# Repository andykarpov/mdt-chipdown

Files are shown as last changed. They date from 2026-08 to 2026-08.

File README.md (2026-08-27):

# MicroDEXED Touch Chipdown custom edition

This is an attempt to create a custom PCB of the MicroDEXED Touch (MDT) project to satisfy my own requirements:

- No modules, all chips should be soldered on PCB
- Avoid THT components as much as possible

**Warning! Work in progress. The revB is untested and unreleased yet.**

- Current tested revision: **revA**
- Current dev revision: **revB**

## PCB changelog & ERRATA:

- revA - initial revision
    - Note: Jumpers to select MIDI IN/OUT standard should be removed, instead of them please use 0 Ohm resistors
    - Latest revA contains the following changes: jumpers replaced with solder jumpers
    - The overall display height is slightly higher than expected. Please use 8.5mm standoffs for it. Also the plastic housing from the display pin headers should be removed and the pin height should be reduced to fit the desired connection height of 8.5mm
- revB:
    - 4-layers PCB
    - Replaced teensy module with a set of chips
    - Added additional SD card
    - Added additional LED from the supplementary MCU
    - Changed USB Host power path

## Rev.A Renders

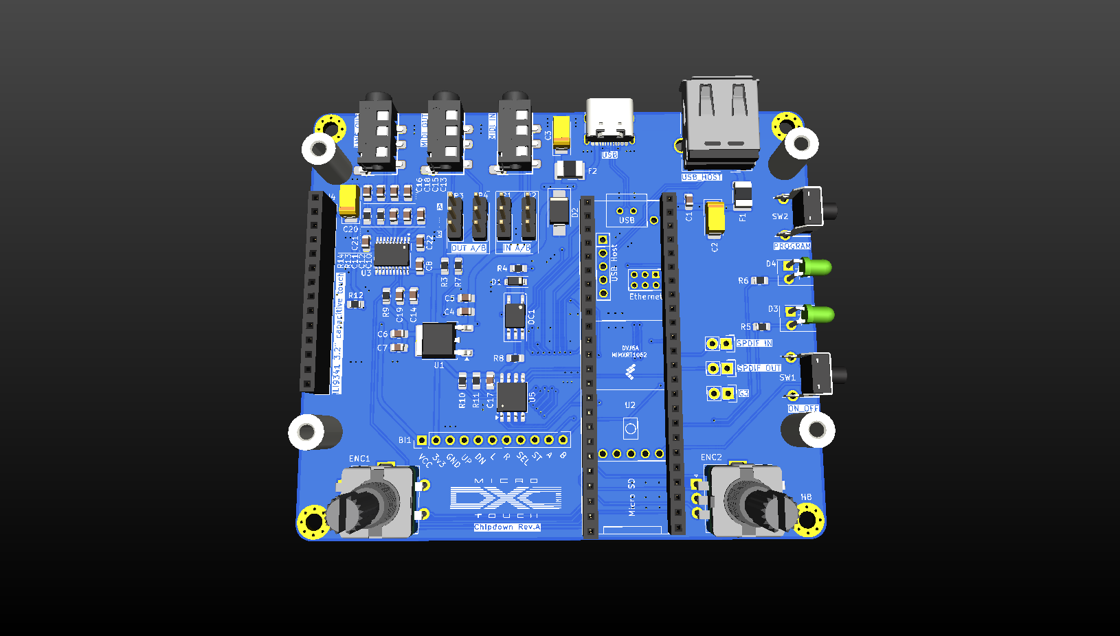
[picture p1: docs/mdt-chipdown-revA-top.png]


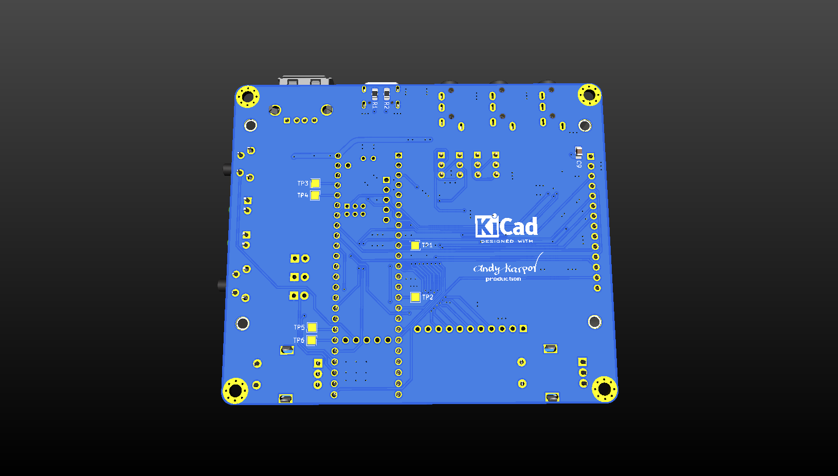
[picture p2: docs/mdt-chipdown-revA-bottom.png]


## Case for rev.A

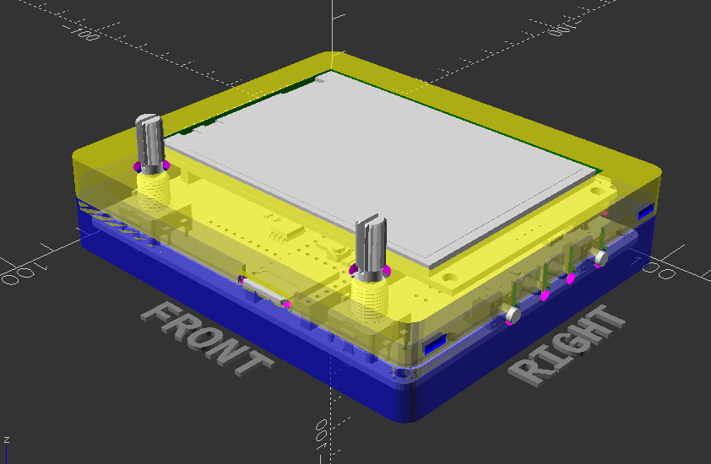
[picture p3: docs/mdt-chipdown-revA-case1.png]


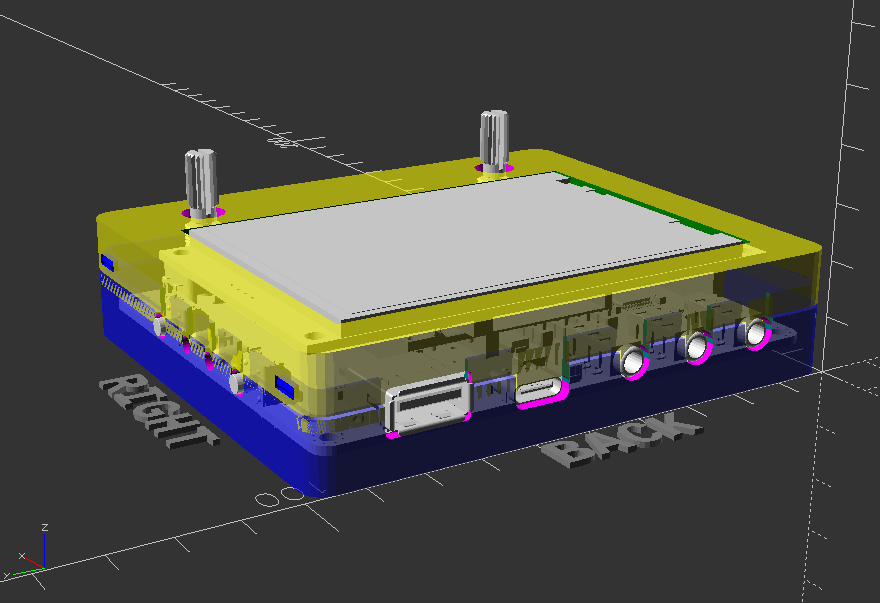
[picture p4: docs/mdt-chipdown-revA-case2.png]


## Rev.B Renders

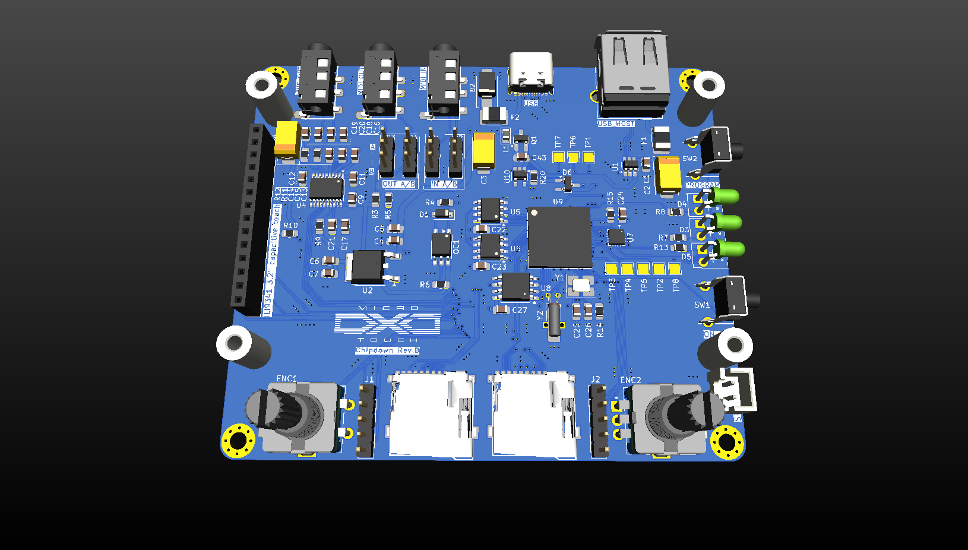
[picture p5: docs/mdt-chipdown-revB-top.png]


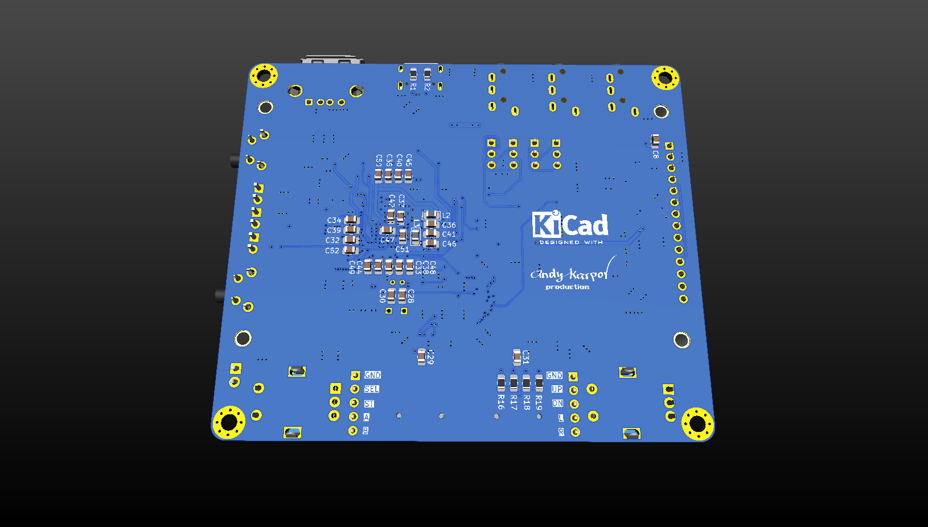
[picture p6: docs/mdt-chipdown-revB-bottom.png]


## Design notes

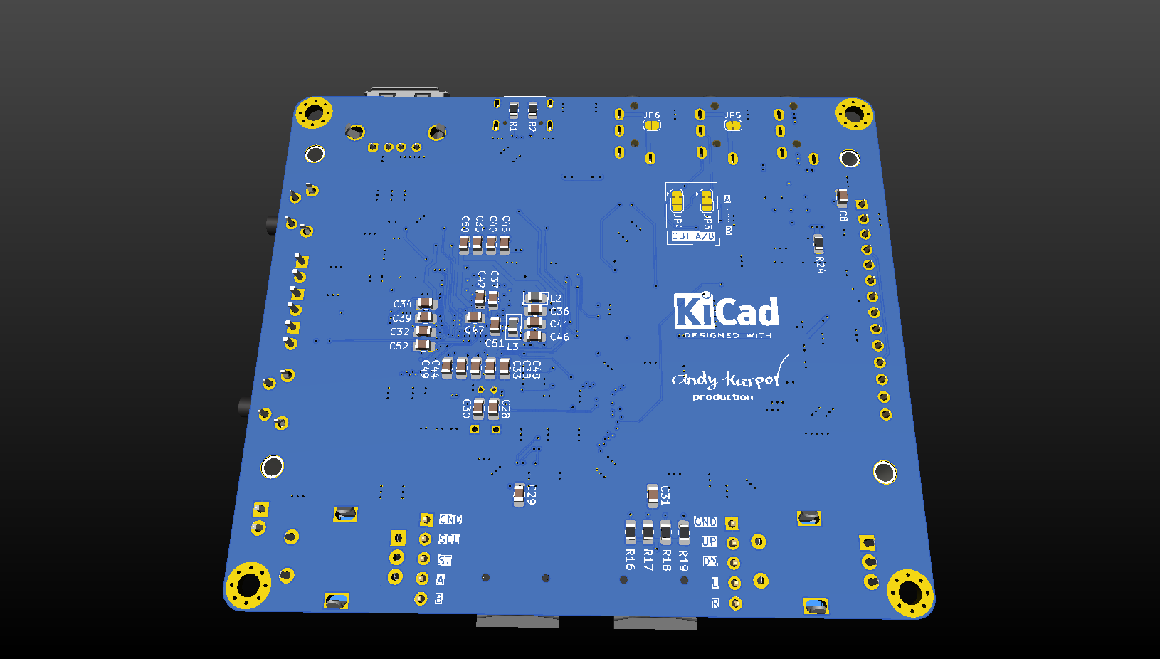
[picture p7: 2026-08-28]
docs/mdt-chipdown-revB1-bottom.png

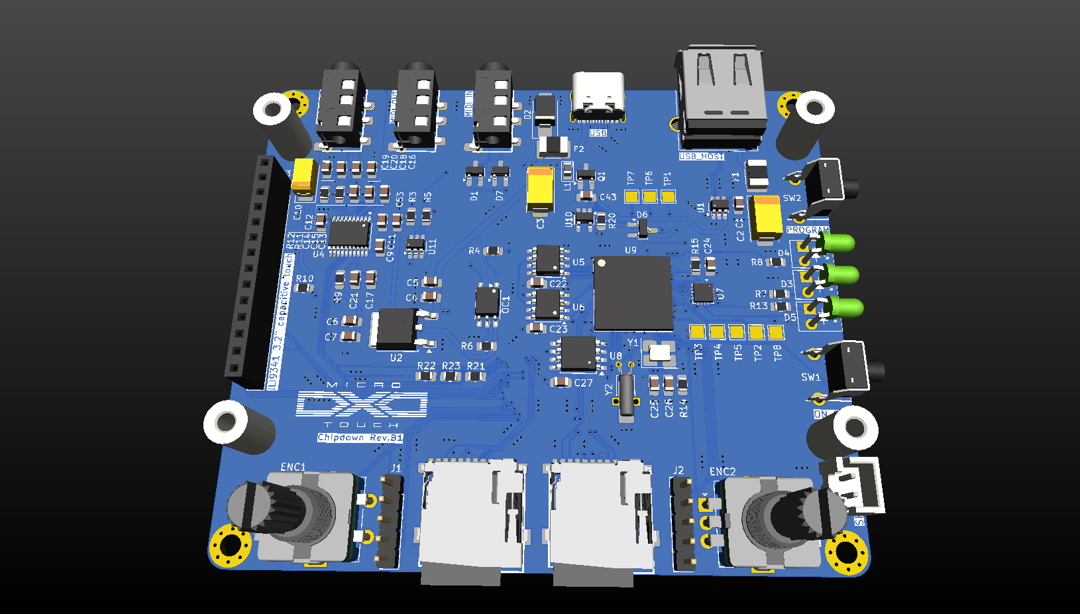
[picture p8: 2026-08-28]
docs/mdt-chipdown-revB1-top.png

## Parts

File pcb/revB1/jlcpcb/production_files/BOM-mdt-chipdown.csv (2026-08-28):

Comment | Designator | Footprint | LCSC | Quantity
0 | R10 | R_0805_2012Metric_Pad1.20x1.40mm_HandSolder | C17477 | 1
100k | R15,R20 | R_0805_2012Metric_Pad1.20x1.40mm_HandSolder | C25611 | 2
100n | C11,C12,C15,C21,C22,C23,C24,C27,C29,C31,C5,C53,C7,C8,C9 | C_0805_2012Metric_Pad1.18x1.45mm_HandSolder | C1711 | 15
100uF | C2,C3 | CP_EIA-7343-31_Kemet-D_HandSolder | C2749 | 2
100uF | C10 | CP_EIA-6032-28_Kemet-C_HandSolder | C8649 | 1
10k | R16,R17,R18,R19 | R_0805_2012Metric_Pad1.20x1.40mm_HandSolder | C17414 | 4
10n | C50,C51 | C_0805_2012Metric_Pad1.18x1.45mm_HandSolder | C1710 | 2
10u | C1,C14,C17,C18,C20,C34,C36,C4,C6 | C_0805_2012Metric_Pad1.18x1.45mm_HandSolder | C15850 | 9
10u | C37 | C_0805_2012Metric | C1713 | 1
12p | C25,C26 | C_0805_2012Metric_Pad1.18x1.45mm_HandSolder | C152848 | 2
1k | R13,R7,R8,R9 | R_0805_2012Metric_Pad1.20x1.40mm_HandSolder | C17513 | 4
20p | C28,C30 | C_0805_2012Metric_Pad1.18x1.45mm_HandSolder | C1727 | 2
220 | R4 | R_0805_2012Metric_Pad1.20x1.40mm_HandSolder | C17557 | 1
220n | C32,C38,C39,C43,C45,C46,C47,C48,C49,C52 | C_0805_2012Metric_Pad1.18x1.45mm_HandSolder | C5378 | 10
24MHz | Y1 | Crystal_SMD_3225-4Pin_3.2x2.5mm_HandSoldering | C15643 | 1
2A | F1,F2 | Fuse_1812_4532Metric_Pad1.30x3.40mm_HandSolder | C20812 | 2
2M2 | R14 | R_0805_2012Metric_Pad1.20x1.40mm_HandSolder | C26113 | 1
2n2 | C16,C19 | C_0805_2012Metric_Pad1.18x1.45mm_HandSolder | C1728 | 2
2u2 | C13,C35 | C_0805_2012Metric_Pad1.18x1.45mm_HandSolder | C19110 | 2
32768 | Y2 | Crystal_C26-LF_D2.1mm_L6.5mm_Horizontal_1EP_style2 | C2236 | 1
47 | R3,R5 | R_0805_2012Metric_Pad1.20x1.40mm_HandSolder | C25315 | 2
470 | R11,R12,R6 | R_0805_2012Metric_Pad1.20x1.40mm_HandSolder | C17710 | 3
4u7 | C33,C40,C41,C42,C44 | C_0805_2012Metric_Pad1.18x1.45mm_HandSolder | C1779 | 5
4u7 | L3 | L_0805_2012Metric_Pad1.15x1.40mm | C63166 | 1
5k1 | R1,R2 | R_0805_2012Metric_Pad1.20x1.40mm_HandSolder | C26023 | 2
74LVC2G06 | U11 | SOT-23-6_Handsoldering | C402162 | 1
AMS1117-3.3 | U2 | TO-252-2 | C41414107 | 1
APS6404L-3SQR | U5,U6 | SOIC-8_3.9x4.9mm_P1.27mm | C5333729 | 2
BAT54C | D6 | SOT-23_Handsoldering | C37704 | 1
BAT54S | D1,D7 | SOT-23_Handsoldering | C7420333 | 2
BI | J1,J2 | PinHeader_1x05_P2.54mm_Vertical | C5156614 | 2
DMG2305UX | Q1 | SOT-23_Handsoldering | C144153 | 1
Ferrite 120 | L1,L2 | L_0805_2012Metric_Pad1.15x1.40mm_HandSolder | C5671 | 2
GD25Q64ESIGR | U8 | SOIC-8_5.3x5.3mm_P1.27mm | C2831359 | 1
ILI9341 3.2" capacitive touch | U3 | PinSocket_1x14_P2.54mm_Vertical | C124407 | 1
LED1 | D3 | LED_Indicator_D3.0mm_W4.6mm_L6.5mm | C17683617 | 1
LED2 | D4 | LED_Indicator_D3.0mm_W4.6mm_L6.5mm | C473837 | 1
LINE OUT | TRS1 | AUDIO_JACK_3.5MM_SMD_TRRS_rounded_mixed | C53447038 | 1
MCU LED | D5 | LED_Indicator_D3.0mm_W4.6mm_L6.5mm | C19188468 | 1
MIDI IN | TRS3 | AUDIO_JACK_3.5MM_SMD_TRRS_rounded_mixed | C53447038 | 1
MIDI OUT | TRS2 | AUDIO_JACK_3.5MM_SMD_TRRS_rounded_mixed | C53447038 | 1
MIMXRT1062DVJ6B | U9 | BGA196C80P14X14_1200X1200X152 | C3216699 | 1
MKL02Z32VFG4 | U7 | QFN-16-1EP_3x3mm_P0.5mm_EP1.9x1.9mm | C2056583 | 1
Micro_SD_Card | J4,J5 | GCT-MEM2055-00-190-01-A | C91145 | 2
ON_OFF | SW1 | Push_PTH_RA_8-020_h7.5mm | C125050 | 1
PCM5102A | U4 | TSSOP-20_4.4x6.5mm_P0.65mm | C107671 | 1
PROGRAM | SW2 | Push_PTH_RA_8-020_h7.5mm | C125050 | 1
Rotary_Encoder_L | ENC1 | RotaryEncoder_Alps_EC11E-Switch_Vertical_H20mm | C7435302 | 1
Rotary_Encoder_R | ENC2 | RotaryEncoder_Alps_EC11E-Switch_Vertical_H20mm | C7435302 | 1
SM6T6V8A | D2 | D_SMB_Handsoldering | C511038 | 1
SPDIF OUT | J3 | Pin_Header_Straight_1x02 | C5360898 | 1
TLP2362 | OC1 | SO-5-6_4.55x3.7mm_P1.27mm | C37658 | 1
TLV75733PDBV | U10 | SOT-23-5_HandSoldering | C485517 | 1
TPD3S014 | U1 | SOT-23-6_Handsoldering | C87384 | 1
USB | USB2 | USB_C_Receptacle_G-Switch_GT-USB-7010ASV | C165948 | 1
USB_HOST | USB1 | USB_A_Molex_67643_Horizontal | C2346 | 1
~ | H8 | MountingHole_M3 |  | 1
~ | H6 | MountingHole_M3 |  | 1
~ | H4 | MountingHole_M3 |  | 1
~ | H2 | MountingHole_M3 |  | 1

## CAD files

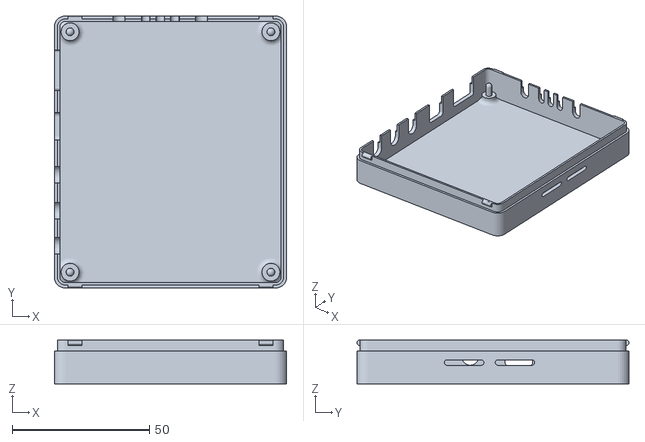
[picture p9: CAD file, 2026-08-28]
case/build/mdt-chipdown-revB-base.stl
84.6 x 99.0 x 16.0

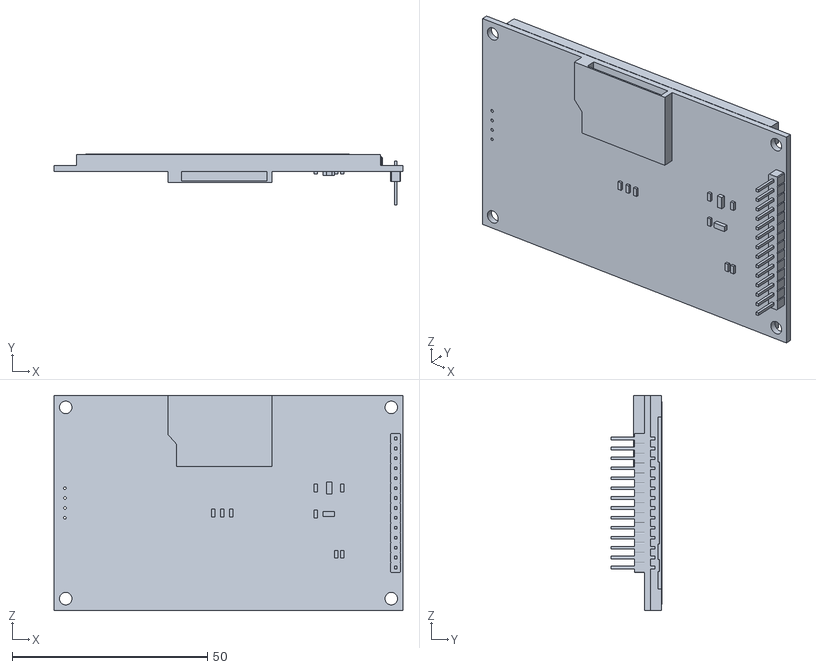
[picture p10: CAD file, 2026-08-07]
case/models/3_2tft.stl
89.4 x 13.1 x 55.1

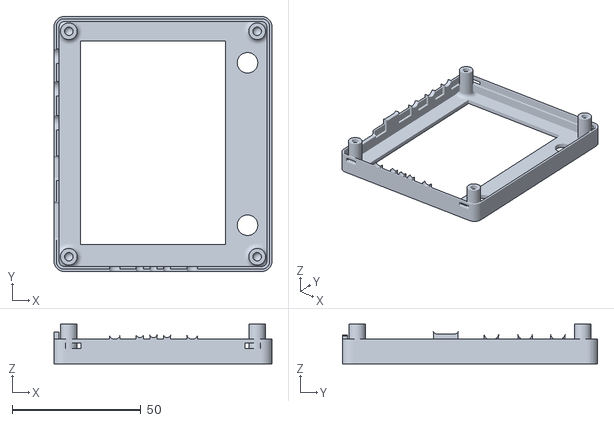
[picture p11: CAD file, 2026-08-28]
case/build/mdt-chipdown-revB-lid.stl
84.6 x 99.0 x 15.5

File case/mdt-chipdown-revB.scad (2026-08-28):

//---------------------------------------------------------
// Yet Another Parameterized Projectbox generator
//
//  This will generate a projectbox for a "MDT Chipdown rev.A"
//
//  Version 3.0 (02-12-2023)
//
// This design is parameterized based on the size of a PCB.
//---------------------------------------------------------
include <./library/YAPPgenerator_v3.scad>

// Note: length/lengte refers to X axis, 
//       width/breedte to Y, 
//       height/hoogte to Z

/*
      padding-back|<------pcb length --->|<padding-front
                            RIGHT
        0    X-as ---> 
        +----------------------------------------+   ---
        |                                        |    ^
        |                                        |   padding-right 
        |                                        |    v
        |    -5,y +----------------------+       |   ---              
 B    Y |         | 0,y              x,y |       |     ^              F
 A    - |         |                      |       |     |              R
 C    a |         |                      |       |     | pcb width    O
 K    s |         |                      |       |     |              N
        |         | 0,0              x,0 |       |     v              T
      ^ |   -5,0  +----------------------+       |   ---
      | |                                        |    padding-left
      0 +----------------------------------------+   ---
        0    X-as --->
                          LEFT
*/

//-- which half do you want to print?
printBaseShell    = true;
printLidShell     = true;
printSwitchExtenders  = false;
printPCB = true;


myPcb = "./models/mdt-chipdown-revB.stl";
myDispPcb = "./models/3_2tft.stl";
offsetDisp = 11+1.6;

if (printPCB)
{
  translate([-31.4, -45.7, 5.1]) 
  {
    rotate([0,0,90]) color("lightgray") import(myPcb);
  }
  
  translate([66.0, 93.6, offsetDisp-3.4]) 
  {
    rotate([90,0,-90]) color("lightgray") import(myDispPcb);
  }
  
}

//-- Edit these parameters for your own board dimensions
wallThickness       = 2;
basePlaneThickness  = 2;
lidPlaneThickness   = 2;

//-- Total height of box = basePlaneThickness + lidPlaneThickness 
//--                     + baseWallHeight + lidWallHeight
//-- space between pcb and lidPlane :=
//--      (baseWallHeight+lidWall_heigth) - (standoff_heigth+pcbThickness)
//--      (6.2 + 4.5) - (3.5 + 1.5) ==> 5.7
baseWallHeight    = 14;
lidWallHeight     = 4.1;

//-- pcb dimensions
pcbLength         = 79.6;
pcbWidth          = 94;
pcbThickness      = 1.6;
                            
//-- padding between pcb and inside wall
paddingFront      = 0.5;
paddingBack       = 0.5;
paddingRight      = 0.5;
paddingLeft       = 0.5;

//-- ridge where base and lid off box can overlap
//-- Make sure this isn't less than lidWallHeight
ridgeHeight       = 4;
ridgeSlack          = 0.2;
roundRadius       = 4.0;
boxType             = 3; // was 0 

//-- How much the PCB needs to be raised from the base
//-- to leave room for solderings and whatnot
standoffHeight    = 3;
standoffPinDiameter = 2.9;
standoffDiameter  = 6.5;

// Set the layer height of your printer
printerLayerHeight  = 0.1; // 0.2


//-- C O N T R O L -------------//-> Default ---------
showSideBySide      = false;     //-> true
previewQuality      = 5;        //-> from 1 to 32, Default = 5
renderQuality       = 8;        //-> from 1 to 32, Default = 8
onLidGap            = 0;
shiftLid            = 1;
hideLidWalls        = false;    //-> false
colorLid            = "yellow";  
alphaLid                  = 0.6;
hideBaseWalls       = false;    //-> false
colorBase           = "blue";
alphaBase           = 0.4;
showPCB             = false;
showSwitches        = false;
showPCBmarkers      = false;
showShellZero       = false;
showCenterMarkers   = false;
inspectX            = 0;        //-> 0=none (>0 from Back)
inspectY            = 0;        //-> 0=none (>0 from Right)
inspectZ            = 0.0;        //-> 0=none (>0 from Bottom)
inspectXfromBack    = false;     //-> View from the inspection cut foreward
inspectYfromLeft    = true;     //-> View from the inspection cut to the right
inspectZfromTop     = true;    //-> View from the inspection cut down
//-- C O N T R O L ---------------------------------------


//===================================================================
// *** PCB Supports ***
// Pin and Socket standoffs 
//-------------------------------------------------------------------
//  Default origin =  yappCoordPCB : pcb[0,0,0]
//
//  Parameters:
//   Required:
//    (0) = posx
//    (1) = posy
//   Optional:
//    (2) = Height to bottom of PCB : Default = standoffHeight
//    (3) = PCB Gap : Default = -1 : Default for yappCoordPCB=pcbThickness, yappCoordBox=0
//    (4) = standoffDiameter    Default = standoffDiameter;
//    (5) = standoffPinDiameter Default = standoffPinDiameter;
//    (6) = standoffHoleSlack   Default = standoffHoleSlack;
//    (7) = filletRadius (0 = auto size)
//    (n) = { <yappBoth> | yappLidOnly | yappBaseOnly }
//    (n) = { yappHole, <yappPin> } // Baseplate support treatment
//    (n) = { <yappAllCorners> | yappFrontLeft | yappFrontRight | yappBackLeft | yappBackRight }
//    (n) = { yappCoordBox, <yappCoordPCB> }  
//    (n) = { yappNoFillet }
//-------------------------------------------------------------------
pcbStands = 
[
  [3.25, 3.25, yappBoth, yappPin, yappAllCorners], // pcb corners
/*  [32.05, 4.06, yappBoth, yappHole, yappFrontLeft, yappFrontRight, yappNoFillet], // front 
  [45.16, 4.06, yappBoth, yappPin, yappBackLeft, yappBackRight, yappNoFillet], // back
  */
];

/*connectors   =  
[
    [4.06, 4.06, 0, 3.5, 5, 3, 5, yappCoordPCB],
    [pcbLength-4.06, 4.06, 0, 3.5, 5, 3, 5, yappCoordPCB],
    [pcbLength-4.06, pcbWidth-4.06, 0, 3.5, 5, 3, 5, yappCoordPCB],
    [4.06, pcbWidth-4.06, 0, 3.5, 5, 3, 5, yappCoordPCB],
];*/

//===================================================================
//  *** Cutouts ***
//    There are 6 cutouts one for each surface:
//      cutoutsBase (Bottom), cutoutsLid (Top), cutoutsFront, cutoutsBack, cutoutsLeft, cutoutsRight
//-------------------------------------------------------------------
//  Default origin = yappCoordBox: box[0,0,0]
//
//                        Required                Not Used        Note
//                      +-----------------------+---------------+------------------------------------
//  yappRectangle       | width, length         | radius        |
//  yappCircle          | radius                | width, length |
//  yappRoundedRect     | width, length, radius |               |     
//  yappCircleWithFlats | width, radius         | length        | length=distance between flats
//  yappCircleWithKey   | width, length, radius |               | width = key width length=key depth
//  yappPolygon         | width, length         | radius        | yappPolygonDef object must be provided
//
//  Parameters:
//   Required:
//    (0) = from Back
//    (1) = from Left
//    (2) = width
//    (3) = length
//    (4) = radius
//    (5) = shape : {yappRectangle | yappCircle | yappPolygon | yappRoundedRect | yappCircleWithFlats | yappCircleWithKey}
//  Optional:
//    (6) = depth : Default = 0/Auto : 0 = Auto (plane thickness)
//    (7) = angle : Default = 0
//    (n) = { yappPolygonDef } : Required if shape = yappPolygon specified -
//    (n) = { yappMaskDef } : If a yappMaskDef object is added it will be used as a mask for the cutout.
//    (n) = { [yappMaskDef, hOffset, vOffst, rotation] } : If a list for a mask is added it will be used as a mask for the cutout. With the Rotation and offsets applied. This can be used to fine tune the mask placement within the opening.
//    (n) = { <yappCoordBox> | yappCoordPCB }
//    (n) = { <yappOrigin>, yappCenter }
//  (n) = { yappLeftOrigin, <yappGlobalOrigin> } // Only affects Top(lid), Back and Right Faces
//-------------------------------------------------------------------
cutoutsLid =  
[
    [72.6, 15.5, 0, 0, 4.0, yappCircle, yappCenter, yappCoordPCB], // ENC1
    [72.6, 78.5, 0, 0, 4.0, yappCircle, yappCenter, yappCoordPCB], // ENC2
];
              
//-- base plane    -- origin is pcb[0,0,0]
// (0) = posx
// (1) = posy
cutoutsBase =   
[
];

//-- back plane  -- origin is pcb[0,0,0]
// (0) = posy
// (1) = posz
cutoutsBack = 
[
    [76.8, 4.2, 14.8, 8, 1, yappRoundedRect, yappCenter, yappCoordPCB], // USB Host
    [56.4, 1.8, 10, 4, 1.5, yappRoundedRect, yappCenter, yappCoordPCB], // usb-c
    [38.7, 3.2, 0, 0, 3.0, yappCircle, yappCenter, yappCoordPCB], // Midi in
    [25.6, 3.2, 0, 0, 3.0, yappCircle, yappCenter, yappCoordPCB], // Audio
    [12.9, 3.2, 0, 0, 3.0, yappCircle, yappCenter, yappCoordPCB], // Midi out
];

ridgeExtBack = 
[
    [71.9, 14.8, 7.8, yappCoordBox], // up on usb-a
    [53.9, 10.0, 8.8, yappCoordBox], // up on usb-c
    [38.2, 6, 9.8, yappCoordBox], // Midi in
    [25.1, 6, 9.8, yappCoordBox], // Midi out
    [12.4, 6, 9.8, yappCoordBox], // Audio out
];
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

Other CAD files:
case/build/mdt-chipdown-revA-base.stl
case/build/mdt-chipdown-revA-lid.stl
case/mdt-chipdown-revA.scad

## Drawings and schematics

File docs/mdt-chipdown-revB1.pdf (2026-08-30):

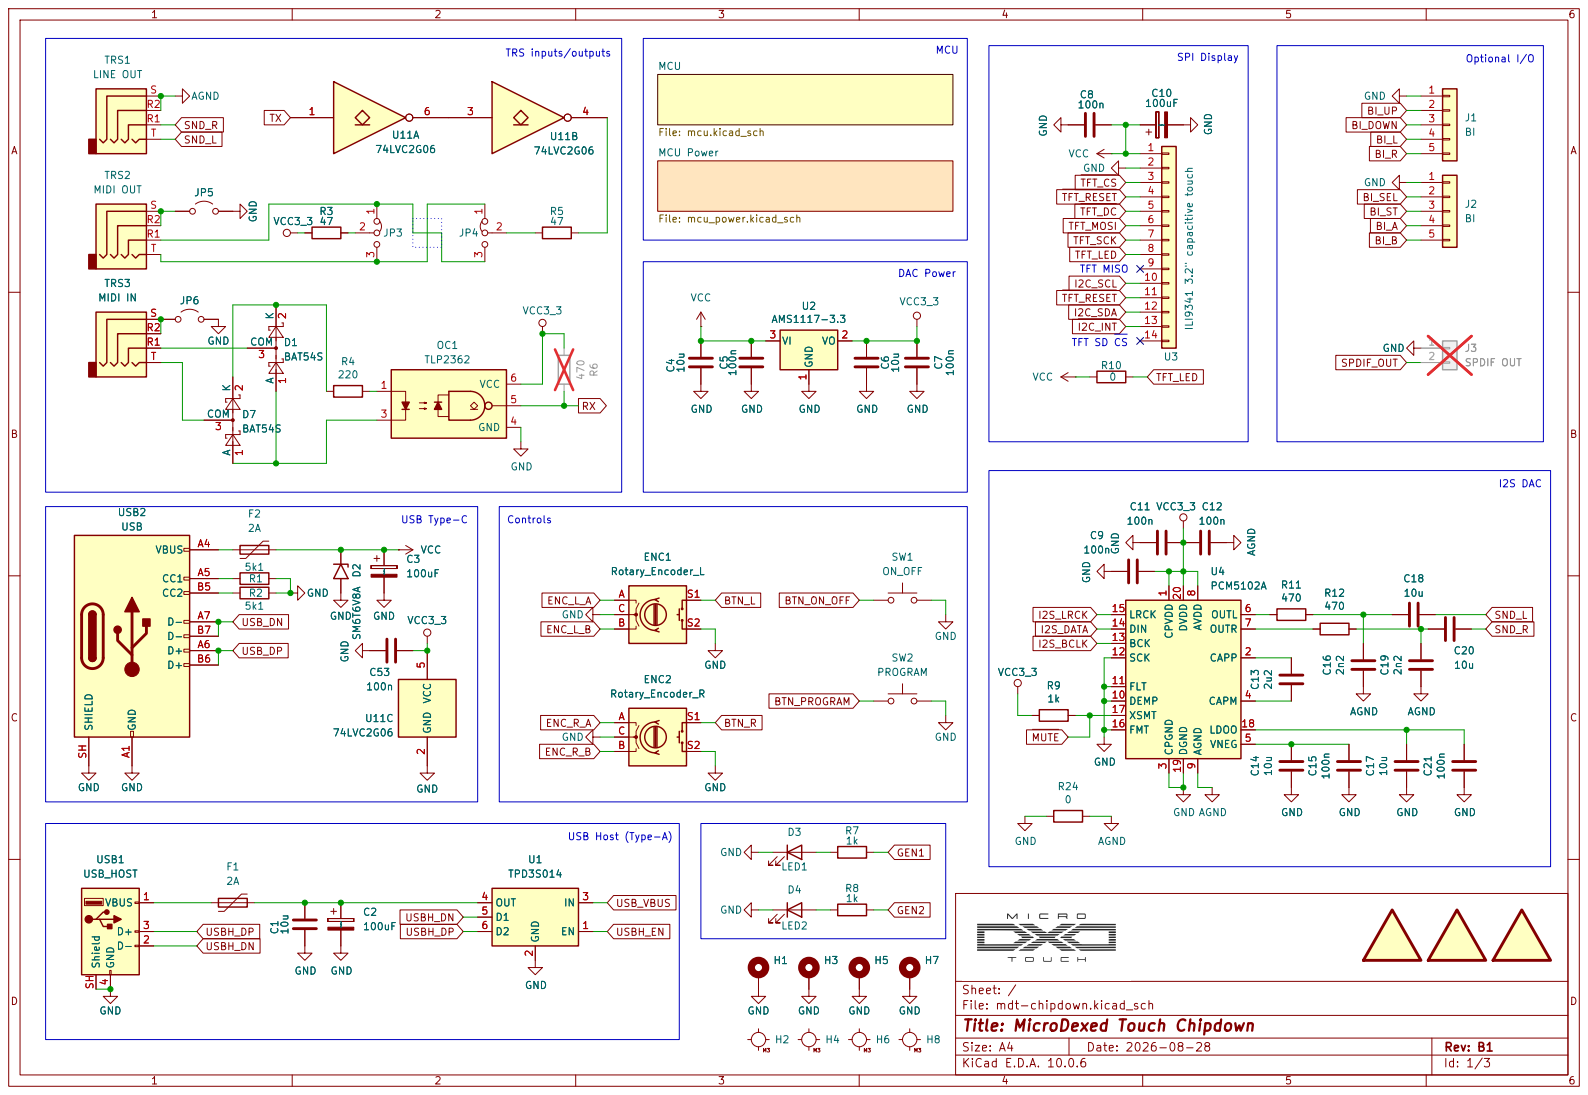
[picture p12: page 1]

I2S DAC Optional I/O TRS inputs/outputs

File: mcu.kicad_sch MCU Power File: mcu_power.kicad_sch GND

SCK 12 BCK 13 DIN 14 LRCK 15

4 Shield SH GND C110u GND

Andy Karpov
Sheet: /
File: mdt-chipdown.kicad_sch
Title: MicroDexed Touch Chipdown

Size: A4 | Rev: B1
KiCad E.D.A. 10.0.6 | Id: 1/3

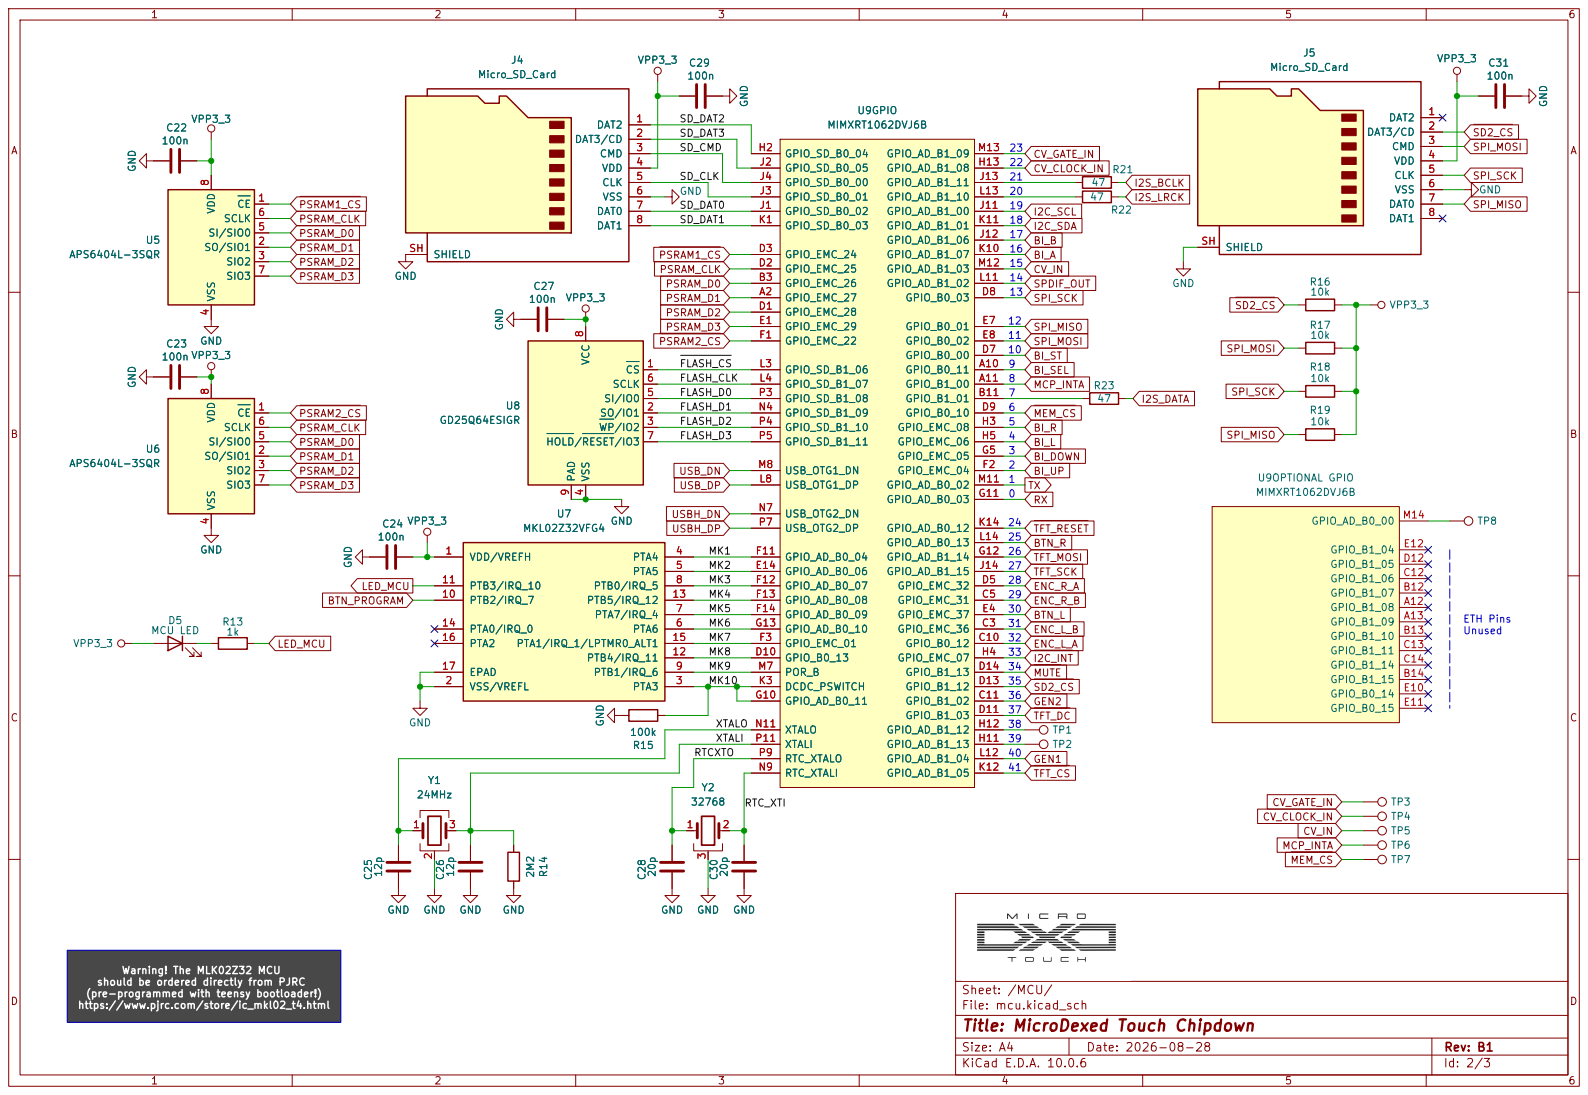
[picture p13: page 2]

APS6404L-3SQR
ETH Pins Unused 0 Warning! The MLK02Z32 MCU should be ordered directly from PJRC

Andy Karpov
Sheet: /MCU/
File: mcu.kicad_sch
Title: MicroDexed Touch Chipdown

(pre-programmed with teensy bootloader!) https://www.pjrc.com/store/ic_mkl02_t4.html

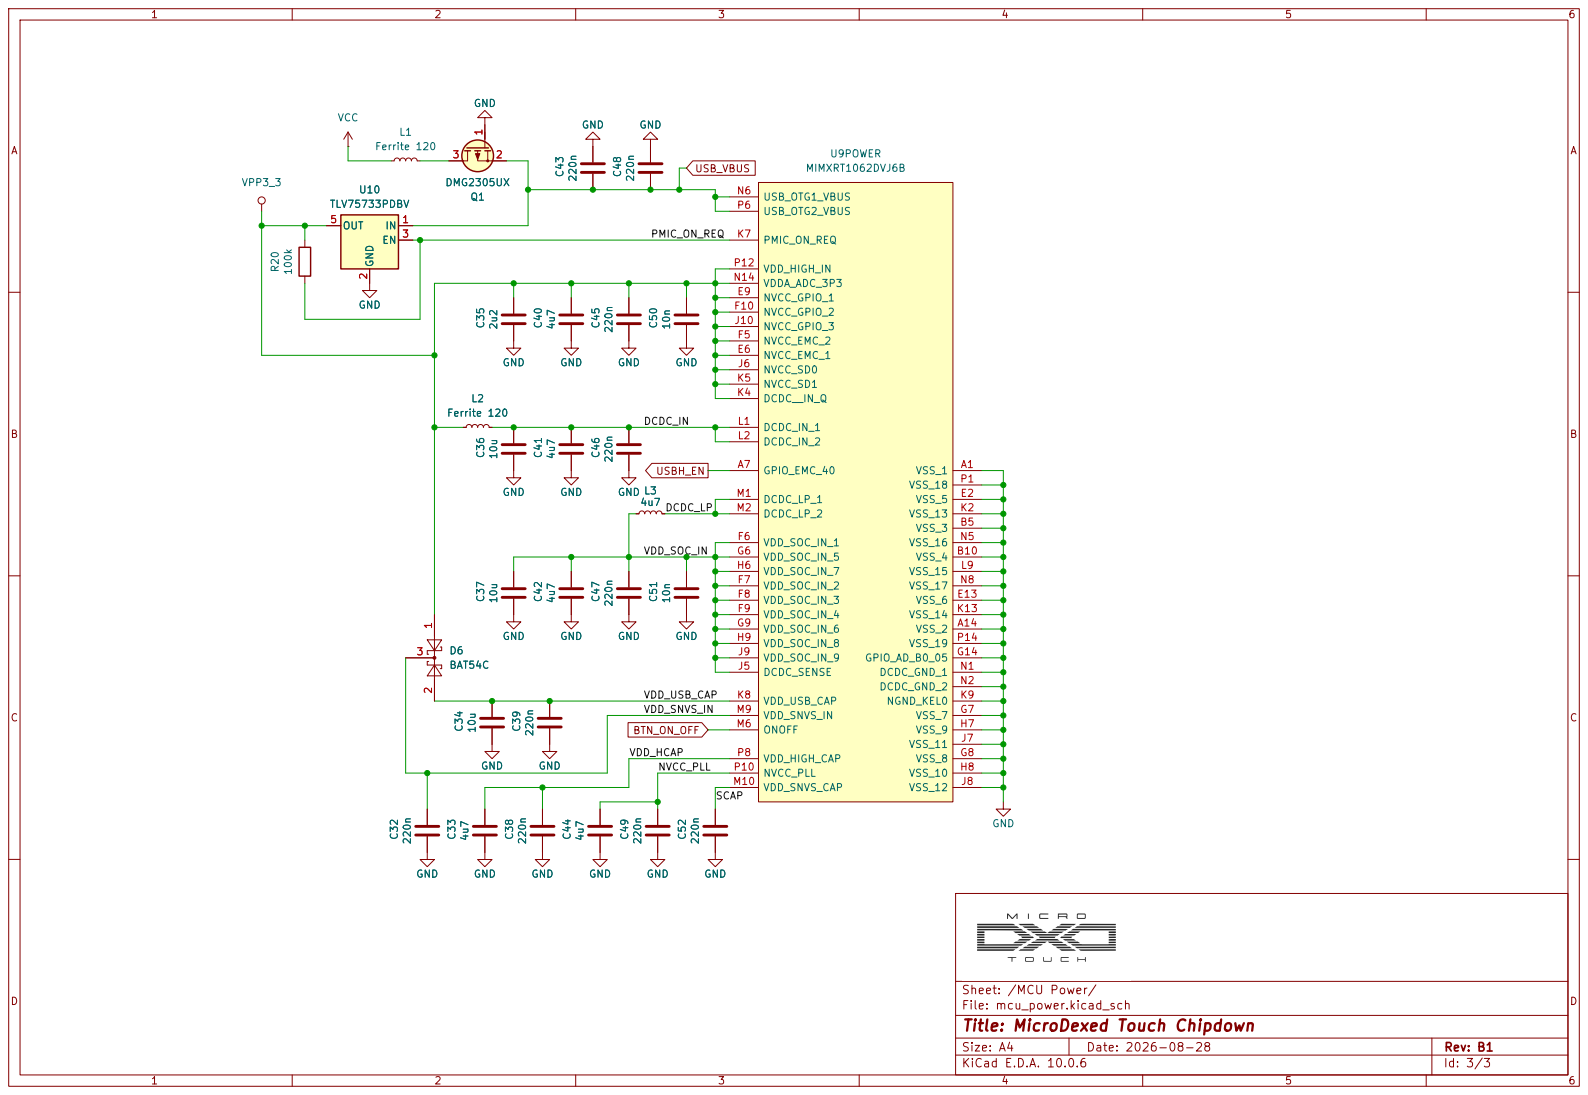
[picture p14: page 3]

Sheet: /MCU Power/
File: mcu_power.kicad_sch
Title: MicroDexed Touch Chipdown

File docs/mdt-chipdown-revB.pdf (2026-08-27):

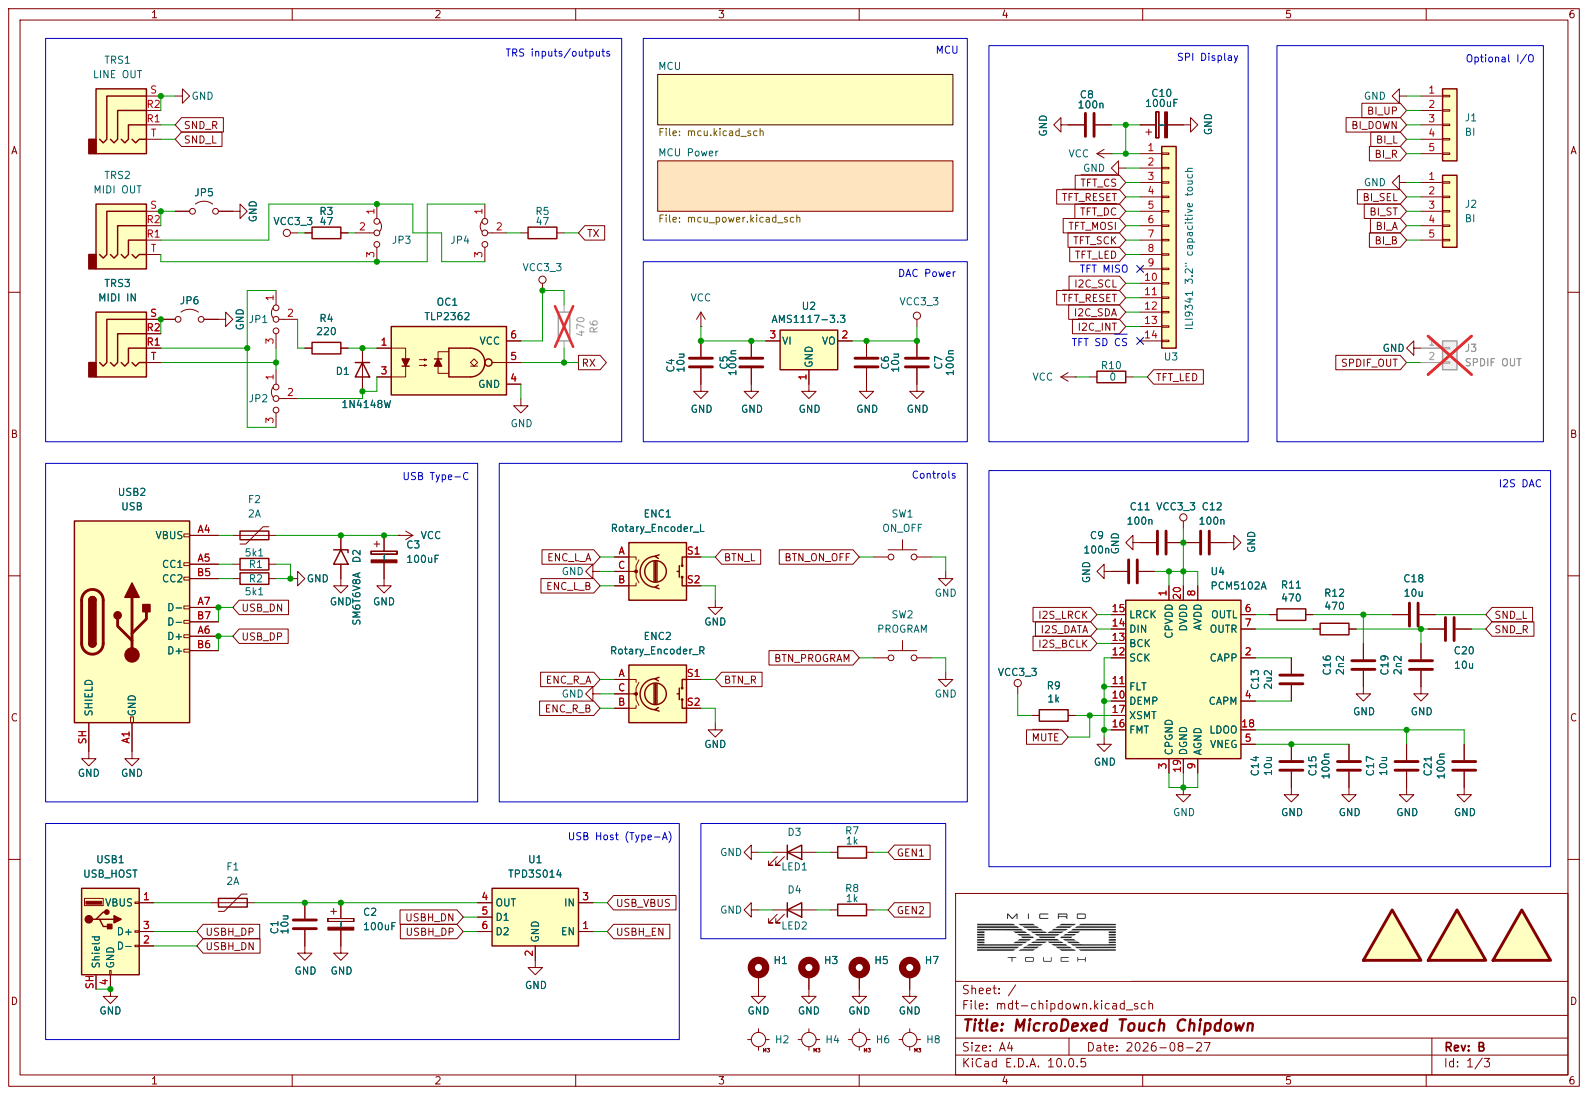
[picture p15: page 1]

File: mcu.kicad_sch MCU Power File: mcu_power.kicad_sch

SCK 12 BCK 13 DIN 14 LRCK 15

Andy Karpov
Sheet: /
File: mdt-chipdown.kicad_sch
Title: MicroDexed Touch Chipdown

Size: A4 | Rev: B
KiCad E.D.A. 10.0.5 | Id: 1/3

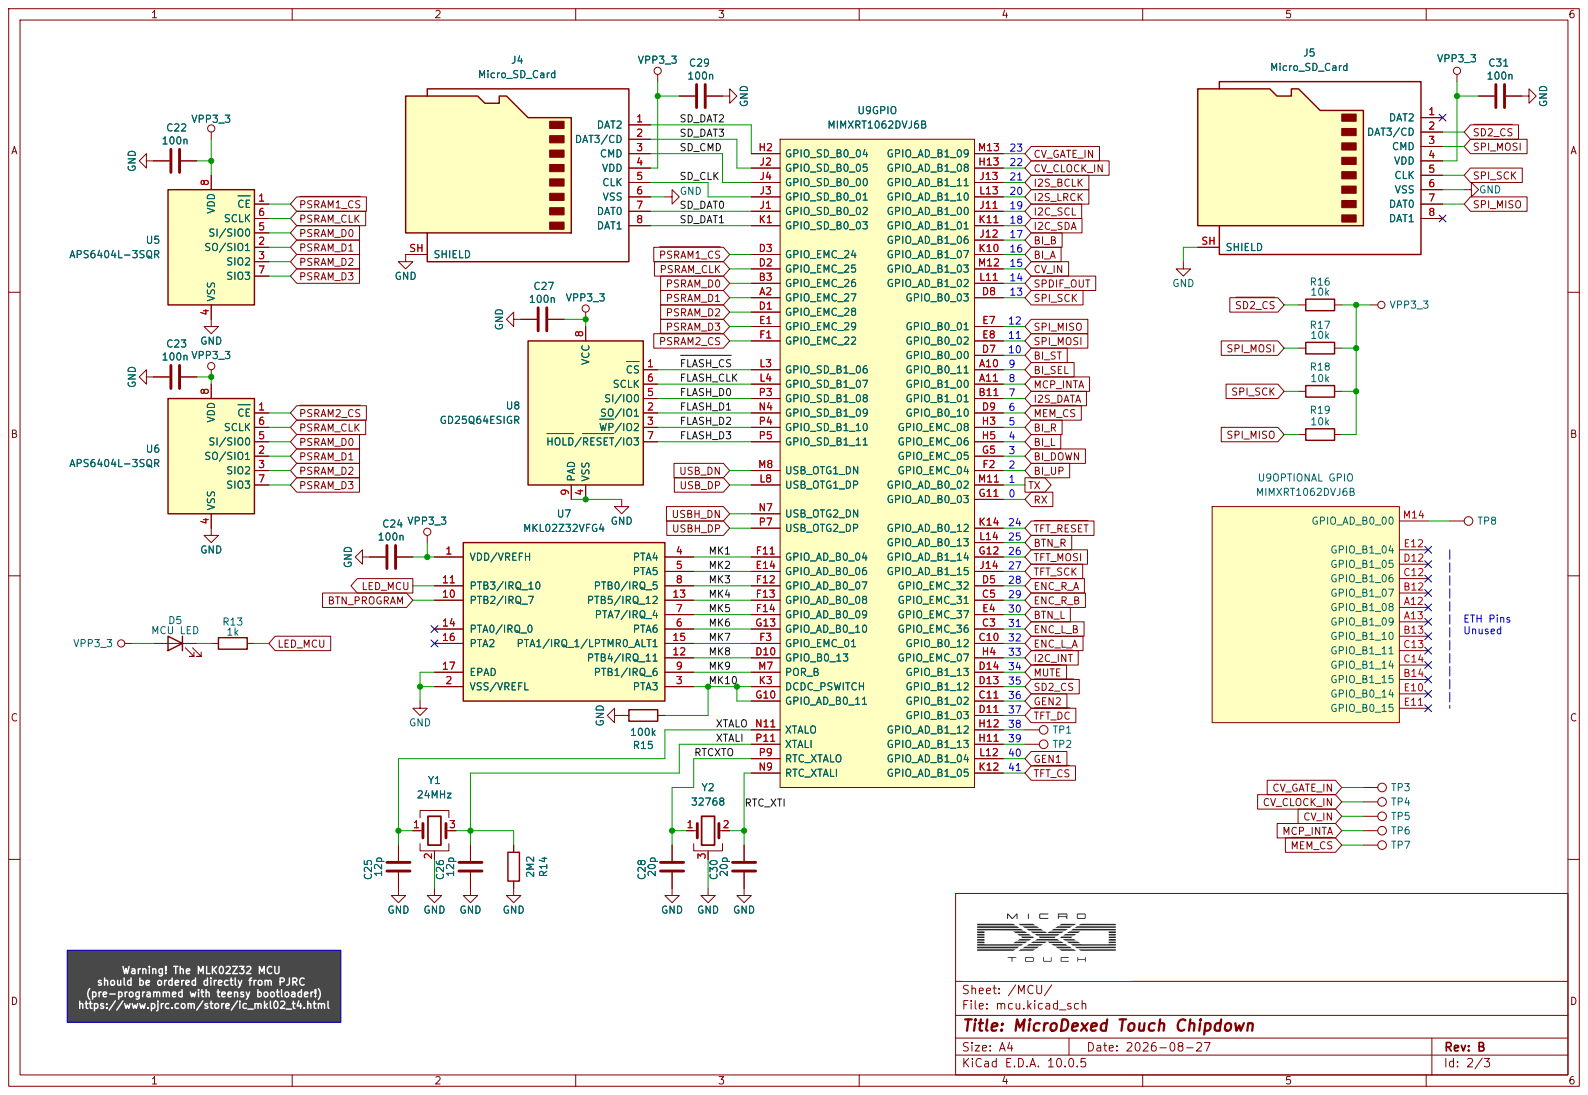
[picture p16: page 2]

40 Warning! The MLK02Z32 MCU should be ordered directly from PJRC

Andy Karpov
Sheet: /MCU/
File: mcu.kicad_sch
Title: MicroDexed Touch Chipdown

(pre-programmed with teensy bootloader!) https://www.pjrc.com/store/ic_mkl02_t4.html

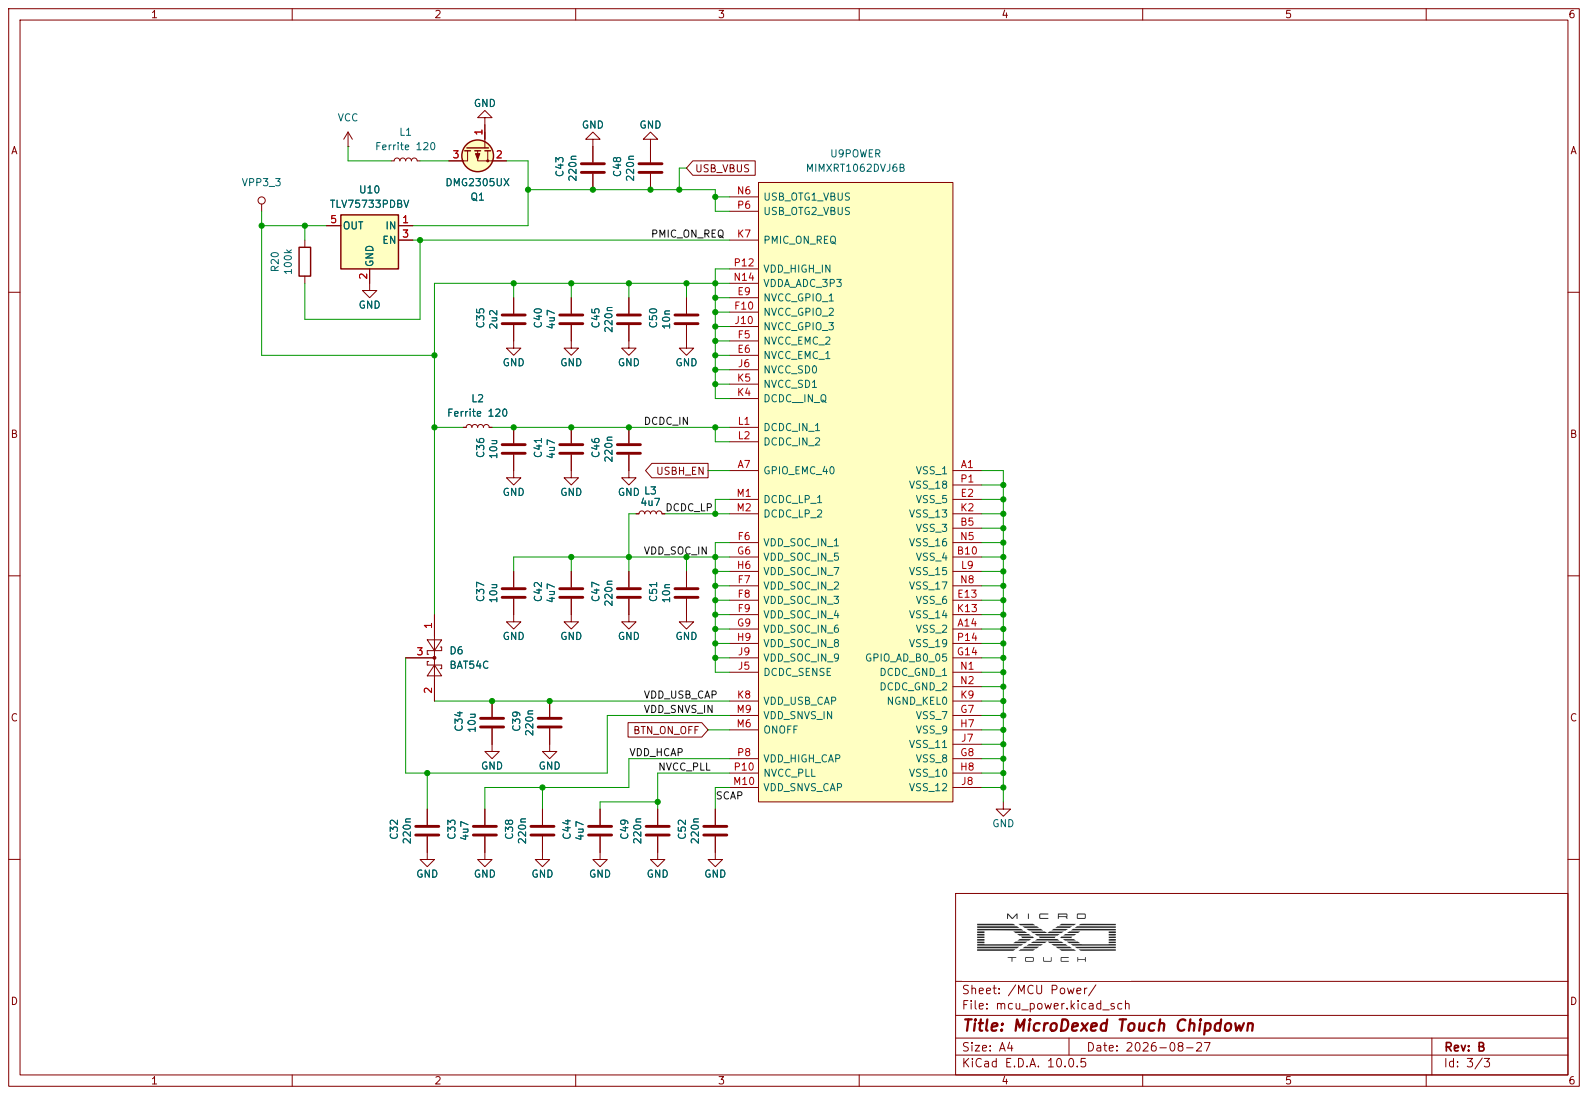
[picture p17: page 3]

Sheet: /MCU Power/
File: mcu_power.kicad_sch
Title: MicroDexed Touch Chipdown

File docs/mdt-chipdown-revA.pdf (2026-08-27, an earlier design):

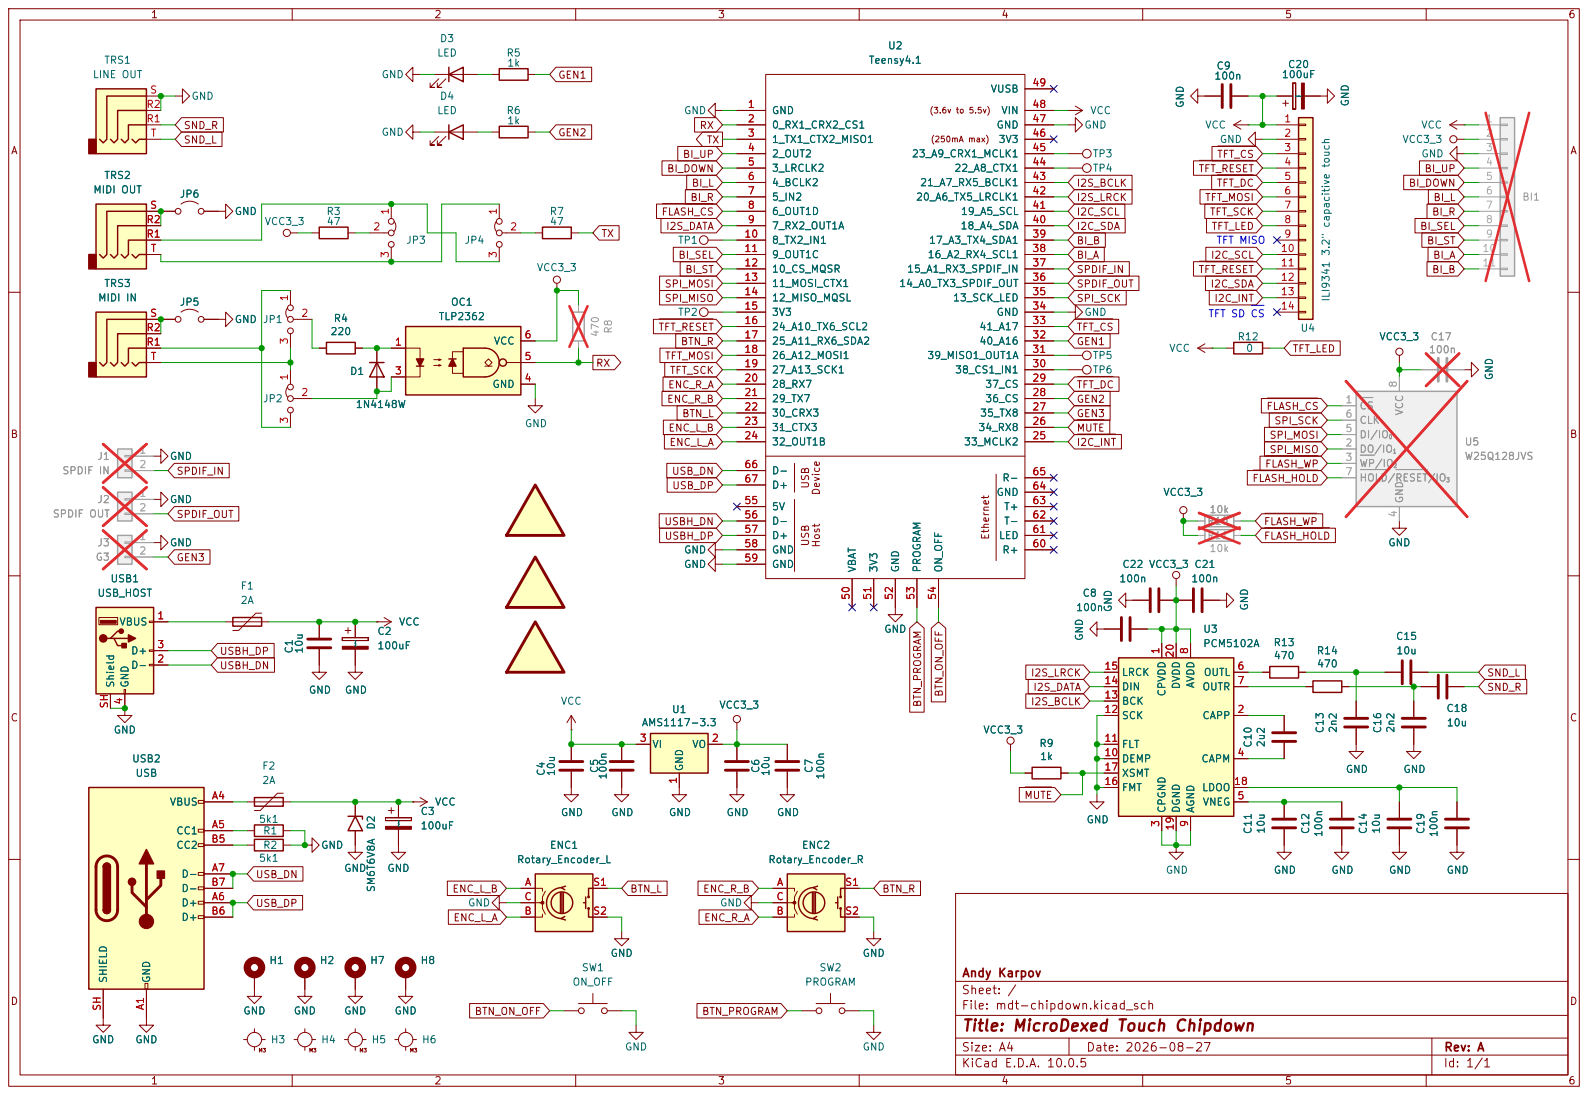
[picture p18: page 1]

SPI_SCK BTN_PROGRAM
TFT SD CS GND

4 DI/IO0 5 CLK 6 HOLD/RESET/IO3 7 VCC

LDOO 18 DGND 19 DVDD 20 GND
SCK 12 BCK 13 DIN 14 LRCK 15

Sheet: /
File: mdt-chipdown.kicad_sch
Title: MicroDexed Touch Chipdown

Size: A4 | Rev: A
KiCad E.D.A. 10.0.5 | Id: 1/1

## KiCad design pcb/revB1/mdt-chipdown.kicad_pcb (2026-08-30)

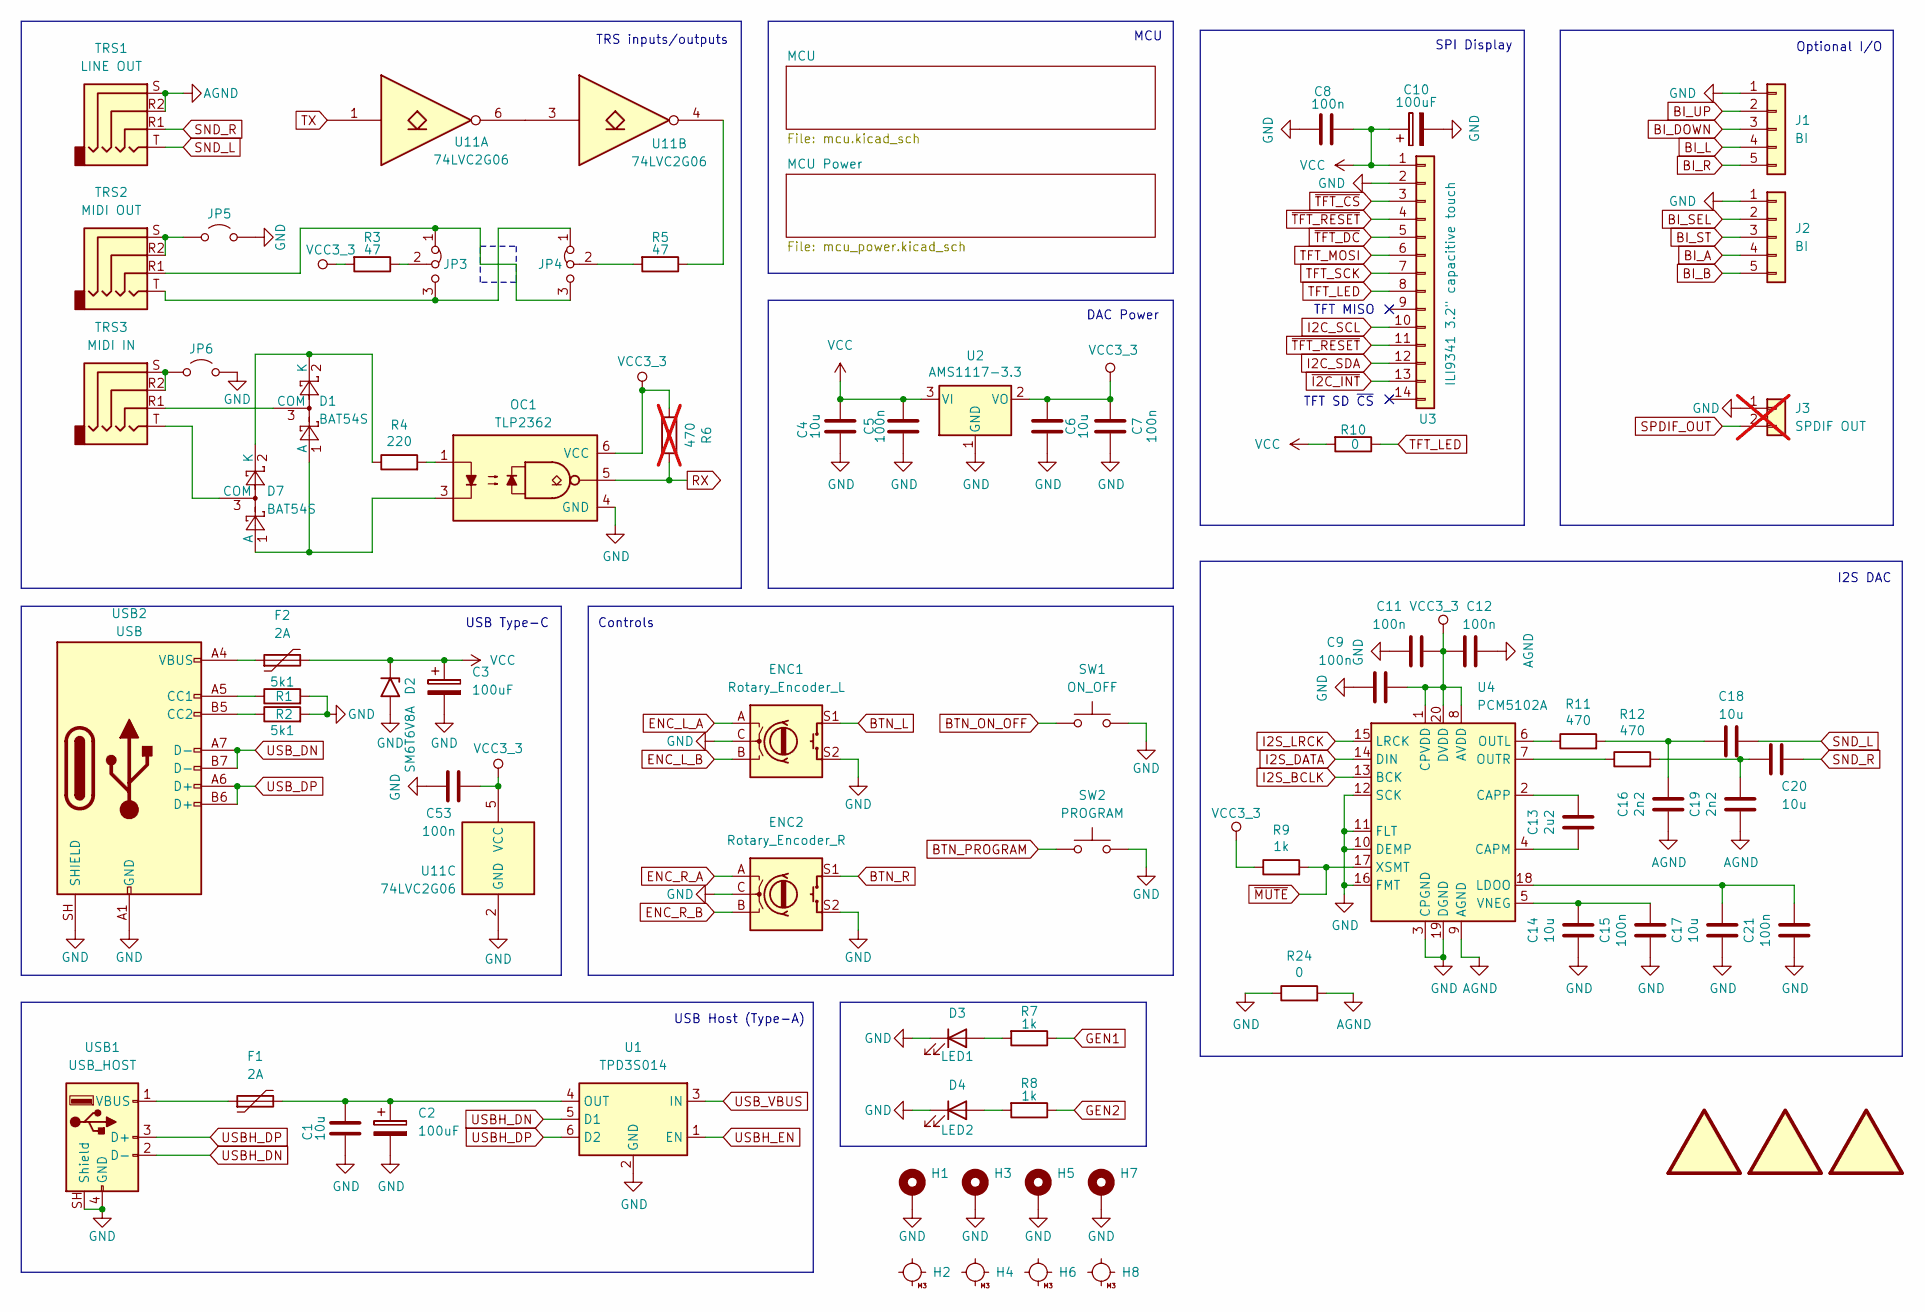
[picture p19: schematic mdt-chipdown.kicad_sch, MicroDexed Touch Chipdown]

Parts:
C1, C4, C6, C14, C17, C18, C20: 10u; C_0805_2012Metric_Pad1.18x1.45mm_HandSolder; LCSC C15850
C2, C3: 100uF; CP_EIA-7343-31_Kemet-D_HandSolder; LCSC C2749
C5, C7, C8, C9, C11, C12, C15, C21, C53: 100n; C_0805_2012Metric_Pad1.18x1.45mm_HandSolder; LCSC C1711
C10: 100uF; CP_EIA-6032-28_Kemet-C_HandSolder; LCSC C8649
C13: 2u2; C_0805_2012Metric_Pad1.18x1.45mm_HandSolder; LCSC C19110
C16, C19: 2n2; C_0805_2012Metric_Pad1.18x1.45mm_HandSolder; LCSC C1728
D1, D7: BAT54S; SOT-23_Handsoldering; LCSC C7420333
D2: SM6T6V8A; D_SMB_Handsoldering; LCSC C511038
D3: LED1; LED_Indicator_D3.0mm_W4.6mm_L6.5mm; LCSC C17683617
D4: LED2; LED_Indicator_D3.0mm_W4.6mm_L6.5mm; LCSC C473837
ENC1: Rotary_Encoder_L; RotaryEncoder_Alps_EC11E-Switch_Vertical_H20mm; LCSC C7435302
ENC2: Rotary_Encoder_R; RotaryEncoder_Alps_EC11E-Switch_Vertical_H20mm; LCSC C7435302
F1, F2: 2A; Fuse_1812_4532Metric_Pad1.30x3.40mm_HandSolder; LCSC C20812
H1, H3, H5, H7: MountingHole_Pad; MountingHole_3mm_Pad_Via
H2, H4, H6, H8: MountingHole_M3
J1, J2: BI; PinHeader_1x05_P2.54mm_Vertical; LCSC C5156614
J3: SPDIF OUT; Pin_Header_Straight_1x02; Part Number 1-0201FBV0T; LCSC C5360898; not fitted
JP3, JP4: Jumper_3_Bridged12; SolderJumper-3_P1.3mm_Bridged12_RoundedPad1.0x1.5mm
JP5: Jumper_2_Open; SolderJumper-2_P1.3mm_Bridged_RoundedPad1.0x1.5mm
JP6: Jumper_2_Open; SolderJumper-2_P1.3mm_Open_RoundedPad1.0x1.5mm
LOGO1: logo; microDXD_logo12
LOGO2: logo; andy_karpov_logo5_silk
LOGO3: logo; KiCad-Logo2_6mm_SilkScreen
OC1: TLP2362; SO-5-6_4.55x3.7mm_P1.27mm; LCSC C37658
R1, R2: 5k1; R_0805_2012Metric_Pad1.20x1.40mm_HandSolder; LCSC C26023
R3, R5: 47; R_0805_2012Metric_Pad1.20x1.40mm_HandSolder; LCSC C25315
R4: 220; R_0805_2012Metric_Pad1.20x1.40mm_HandSolder; LCSC C17557
R6: 470; R_0805_2012Metric_Pad1.20x1.40mm_HandSolder; LCSC C17710; not fitted
R7, R8, R9: 1k; R_0805_2012Metric_Pad1.20x1.40mm_HandSolder; LCSC C17513
R10: 0; R_0805_2012Metric_Pad1.20x1.40mm_HandSolder; LCSC C17477
R11, R12: 470; R_0805_2012Metric_Pad1.20x1.40mm_HandSolder; LCSC C17710
R24: 0; R_0805_2012Metric_Pad1.20x1.40mm_HandSolder; LCSC C17513
SW1: ON_OFF; Push_PTH_RA_8-020_h7.5mm; LCSC C125050
SW2: PROGRAM; Push_PTH_RA_8-020_h7.5mm; LCSC C125050
TRS1: LINE OUT; AUDIO_JACK_3.5MM_SMD_TRRS_rounded_mixed; LCSC C53447038
TRS2: MIDI OUT; AUDIO_JACK_3.5MM_SMD_TRRS_rounded_mixed; LCSC C53447038
TRS3: MIDI IN; AUDIO_JACK_3.5MM_SMD_TRRS_rounded_mixed; LCSC C53447038
U1: TPD3S014; SOT-23-6_Handsoldering; LCSC C87384
U2: AMS1117-3.3; TO-252-2; LCSC C41414107
U3: ILI9341 3.2" capacitive touch; PinSocket_1x14_P2.54mm_Vertical; LCSC C124407
U4: PCM5102A; TSSOP-20_4.4x6.5mm_P0.65mm; LCSC C107671
U11: 74LVC2G06; SOT-23-6_Handsoldering; LCSC C402162
USB1: USB_HOST; USB_A_Molex_67643_Horizontal; LCSC C2346
USB2: USB; USB_C_Receptacle_G-Switch_GT-USB-7010ASV; LCSC C165948

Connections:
AGND: C12.1, C16.1, C19.1, R24.2, TRS1.R2, TRS1.S, U4.9 (AGND)
BI_A: J2.4; also elsewhere on the board
BI_B: J2.5; also elsewhere on the board
BI_DOWN: J1.3; also elsewhere on the board
BI_L: J1.4; also elsewhere on the board
BI_R: J1.5; also elsewhere on the board
BI_SEL: J2.2; also elsewhere on the board
BI_ST: J2.3; also elsewhere on the board
BI_UP: J1.2; also elsewhere on the board
BTN_L: ENC1.S1; also elsewhere on the board
BTN_ON_OFF: SW1.1; also elsewhere on the board
BTN_PROGRAM: SW2.1; also elsewhere on the board
BTN_R: ENC2.S1; also elsewhere on the board
ENC_L_A: ENC1.A; also elsewhere on the board
ENC_L_B: ENC1.B; also elsewhere on the board
ENC_R_A: ENC2.A; also elsewhere on the board
ENC_R_B: ENC2.B; also elsewhere on the board
GEN1: R7.1; also elsewhere on the board
GEN2: R8.1; also elsewhere on the board
GND: C1.2, C2.2, C3.2, C4.2, C5.2, C6.2, C7.2, C8.2, C9.2, C10.2, C11.2, C14.1, C15.1, C17.1, C21.1, C53.2, D2.2 (A2), D3.1 (K), D4.1 (K), ENC1.C, ENC1.S2, ENC2.C, ENC2.S2, H1.1 (1_1), H3.1 (1_1), H5.1 (1_1), H7.1 (1_1), J1.1, J2.1, J3.1, JP5.2 (B), JP6.2 (B), OC1.4 (GND), R1.2, R2.2, R24.1, SW1.2, SW2.2, U1.2 (GND), U2.1 (GND), U3.2, U4.3 (CPGND), U4.10 (DEMP), U4.11 (FLT), U4.12 (SCK), U4.16 (FMT), U4.19 (DGND), U11.2 (GND), USB1.4 (GND), USB1.SH (Shield), USB2.A1 (GND), USB2.A12 (GND), USB2.B1 (GND), USB2.B12 (GND), USB2.SH (SHIELD); also elsewhere on the board
I2C_SCL: U3.10; also elsewhere on the board
I2C_SDA: U3.12; also elsewhere on the board
I2S_BCLK: U4.13 (BCK); also elsewhere on the board
I2S_DATA: U4.14 (DIN); also elsewhere on the board
I2S_LRCK: U4.15 (LRCK); also elsewhere on the board
unnamed: C16.2, C18.2, R11.2
unnamed: C19.2, C20.2, R12.2
unnamed: D1.1 (A), D7.1 (A), OC1.3
unnamed: D1.3 (COM), TRS3.R1
unnamed: D1.2 (K), D7.2 (K), R4.1
unnamed: D3.2 (A), R7.2
unnamed: D4.2 (A), R8.2
unnamed: D7.3 (COM), TRS3.T
unnamed: F2.1, USB2.A4 (VBUS), USB2.A9 (VBUS), USB2.B4 (VBUS), USB2.B9 (VBUS)
unnamed: JP3.1 (A), JP4.3 (B), TRS2.R1
unnamed: JP3.3 (B), JP4.1 (A), TRS2.T
unnamed: JP3.2 (C), R3.1
unnamed: JP4.2 (C), R5.2
unnamed: JP5.1 (A), TRS2.R2, TRS2.S
unnamed: JP6.1 (A), TRS3.R2, TRS3.S
unnamed: OC1.1, R4.2
unnamed: R5.1, U11.4
unnamed: C1.1, C2.1, F1.2, U1.4 (OUT)
unnamed: C13.1, U4.4 (CAPM)
unnamed: C13.2, U4.2 (CAPP)
unnamed: C17.2, C21.2, U4.18 (LDOO)
unnamed: R11.1, U4.6 (OUTL)
unnamed: R12.1, U4.7 (OUTR)
unnamed: C14.2, C15.2, U4.5 (VNEG)
unnamed: U11.3, U11.6
unnamed: F1.1, USB1.1 (VBUS)
unnamed: R1.1, USB2.A5 (CC1)
unnamed: R2.1, USB2.B5 (CC2)
RX: OC1.5, R6.2; also elsewhere on the board
SND_L: C18.1, TRS1.T
SND_R: C20.1, TRS1.R1
SPDIF_OUT: J3.2; also elsewhere on the board
TFT_LED: R10.1, U3.8
TFT_MOSI: U3.6; also elsewhere on the board
TFT_SCK: U3.7; also elsewhere on the board
TX: U11.1; also elsewhere on the board
USBH_DN: U1.5 (D1), USB1.2 (D-); also elsewhere on the board
USBH_DP: U1.6 (D2), USB1.3 (D+); also elsewhere on the board
USBH_EN: U1.1 (EN); also elsewhere on the board
USB_DN: USB2.A7 (D-), USB2.B7 (D-); also elsewhere on the board
USB_DP: USB2.A6 (D+), USB2.B6 (D+); also elsewhere on the board
USB_VBUS: U1.3 (IN); also elsewhere on the board
VCC: C3.1, C4.1, C5.1, C8.1, C10.1, D2.1 (A1), F2.2, R10.2, U2.3 (VI), U3.1; also elsewhere on the board
VCC3_3: C6.1, C7.1, C9.1, C11.1, C12.2, C53.1, OC1.6 (VCC), R3.2, R6.1, R9.1, U2.2 (VO), U4.1 (CPVDD), U4.8 (AVDD), U4.20 (DVDD), U11.5 (VCC)
~I2C_INT: U3.13; also elsewhere on the board
~MUTE: R9.2, U4.17 (XSMT); also elsewhere on the board
~TFT_CS: U3.3; also elsewhere on the board
~TFT_DC: U3.5; also elsewhere on the board
~TFT_RESET: U3.4, U3.11; also elsewhere on the board

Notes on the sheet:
TRS inputs/outputs
I2S DAC
TFT SD ~{CS}
DAC Power
MCU
Optional I/O
SPI Display
TFT MISO
USB Host (Type-A)
Controls
USB Type-C

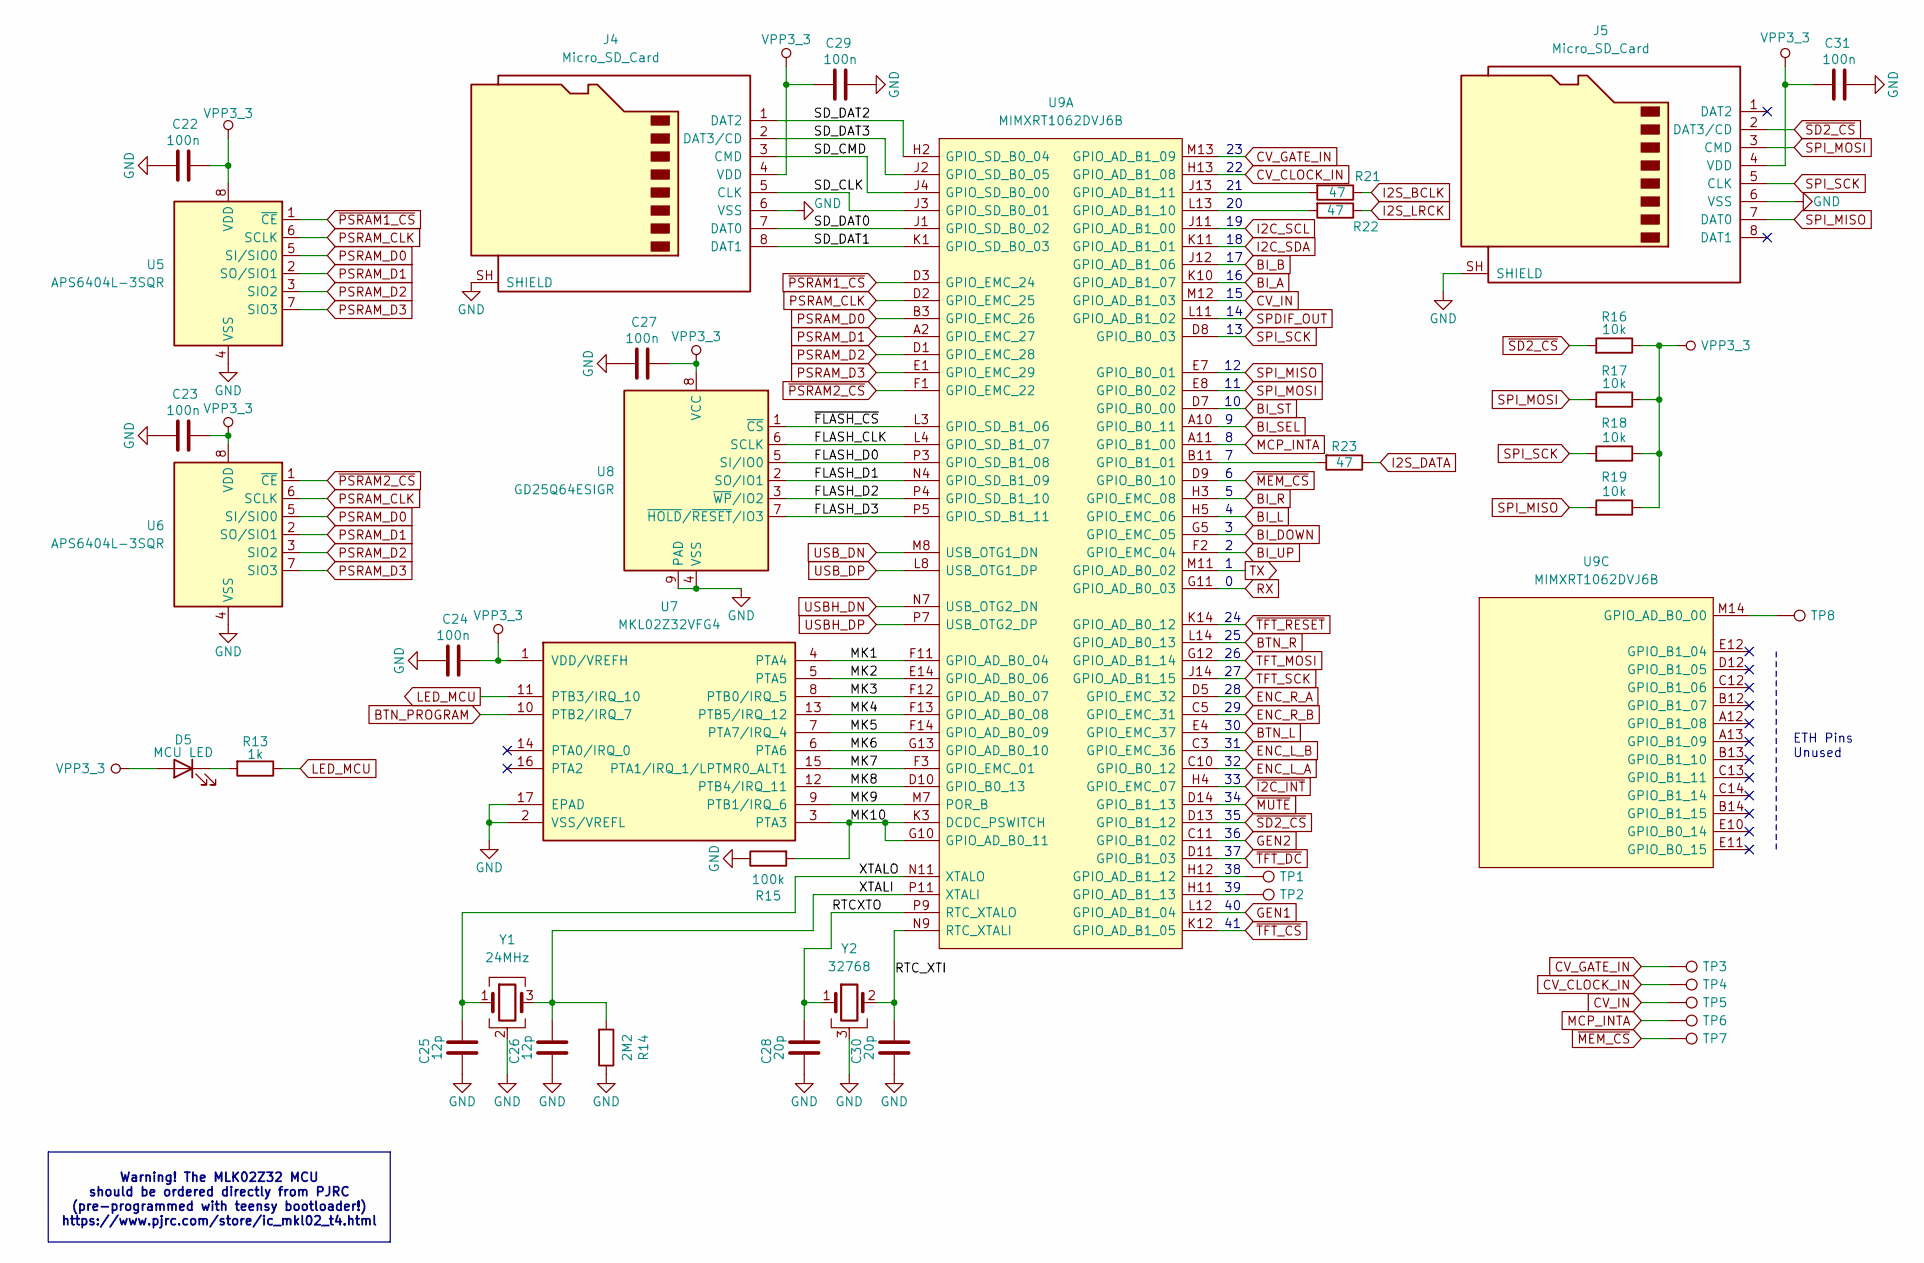
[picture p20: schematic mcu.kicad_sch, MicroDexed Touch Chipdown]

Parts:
C22, C23, C24, C27, C29, C31: 100n; C_0805_2012Metric_Pad1.18x1.45mm_HandSolder; LCSC C1711
C25, C26: 12p; C_0805_2012Metric_Pad1.18x1.45mm_HandSolder; LCSC C152848
C28, C30: 20p; C_0805_2012Metric_Pad1.18x1.45mm_HandSolder; LCSC C1727
D5: MCU LED; LED_Indicator_D3.0mm_W4.6mm_L6.5mm; LCSC C19188468
J4, J5: Micro_SD_Card; GCT-MEM2055-00-190-01-A; LCSC C91145
R13: 1k; R_0805_2012Metric_Pad1.20x1.40mm_HandSolder; LCSC C17513
R14: 2M2; R_0805_2012Metric_Pad1.20x1.40mm_HandSolder; LCSC C26113
R15: 100k; R_0805_2012Metric_Pad1.20x1.40mm_HandSolder; LCSC C25611
R16, R17, R18, R19: 10k; R_0805_2012Metric_Pad1.20x1.40mm_HandSolder; LCSC C17414
R21, R22, R23: 47; R_0805_2012Metric_Pad1.20x1.40mm_HandSolder; LCSC C25315
TP1: GPIO_AD_B1_12; TestPoint_Pad_2.0x2.0mm
TP2: GPIO_AD_B1_13; TestPoint_Pad_2.0x2.0mm
TP3: CV GATE IN; TestPoint_Pad_2.0x2.0mm
TP4: CV CLOCK IN; TestPoint_Pad_2.0x2.0mm
TP5: CV IN; TestPoint_Pad_2.0x2.0mm
TP6: MCP INTA; TestPoint_Pad_2.0x2.0mm
TP7: MEM CS; TestPoint_Pad_2.0x2.0mm
TP8: GPIO_AD_B0_00; TestPoint_Pad_2.0x2.0mm
U5, U6: APS6404L-3SQR; SOIC-8_3.9x4.9mm_P1.27mm; LCSC C5333729
U7: MKL02Z32VFG4; QFN-16-1EP_3x3mm_P0.5mm_EP1.9x1.9mm; LCSC C2056583
U8: GD25Q64ESIGR; SOIC-8_5.3x5.3mm_P1.27mm; LCSC C2831359
U9: MIMXRT1062DVJ6B; BGA196C80P14X14_1200X1200X152; Mouser Part Number 771-MIMXRT1062DVJ6B
Y1: 24MHz; Crystal_SMD_3225-4Pin_3.2x2.5mm_HandSoldering; LCSC C15643
Y2: 32768; Crystal_C26-LF_D2.1mm_L6.5mm_Horizontal_1EP_style2; LCSC C2236

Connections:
/MCU/FLASH_CLK: U8.6 (SCLK), U9.L4 (GPIO_SD_B1_07)
/MCU/FLASH_D0: U8.5 (SI/IO0), U9.P3 (GPIO_SD_B1_08)
/MCU/FLASH_D1: U8.2 (SO/IO1), U9.N4 (GPIO_SD_B1_09)
/MCU/FLASH_D2: U8.3 (~WP/IO2), U9.P4 (GPIO_SD_B1_10)
/MCU/FLASH_D3: U8.7 (~HOLD/~RESET/IO3), U9.P5 (GPIO_SD_B1_11)
/MCU/MK1: U7.4 (PTA4), U9.F11 (GPIO_AD_B0_04)
/MCU/MK2: U7.5 (PTA5), U9.E14 (GPIO_AD_B0_06)
/MCU/MK3: U7.8 (PTB0/IRQ_5), U9.F12 (GPIO_AD_B0_07)
/MCU/MK4: U7.13 (PTB5/IRQ_12), U9.F13 (GPIO_AD_B0_08)
/MCU/MK5: U7.7 (PTA7/IRQ_4), U9.F14 (GPIO_AD_B0_09)
/MCU/MK6: U7.6 (PTA6), U9.G13 (GPIO_AD_B0_10)
/MCU/MK7: U7.15 (PTA1/IRQ_1/LPTMR0_ALT1), U9.F3 (GPIO_EMC_01)
/MCU/MK8: U7.12 (PTB4/IRQ_11), U9.D10 (GPIO_B0_13)
/MCU/MK9: U7.9 (PTB1/IRQ_6), U9.M7 (POR_B)
/MCU/MK10: R15.2, U7.3 (PTA3), U9.G10 (GPIO_AD_B0_11), U9.K3 (DCDC_PSWITCH)
/MCU/RTCXTO: C28.1, U9.P9 (RTC_XTALO), Y2.1
/MCU/RTC_XTI: C30.1, U9.N9 (RTC_XTALI), Y2.2
/MCU/SD_CLK: J4.5 (CLK), U9.J3 (GPIO_SD_B0_01)
/MCU/SD_CMD: J4.3 (CMD), U9.J4 (GPIO_SD_B0_00)
/MCU/SD_DAT0: J4.7 (DAT0), U9.J1 (GPIO_SD_B0_02)
/MCU/SD_DAT1: J4.8 (DAT1), U9.K1 (GPIO_SD_B0_03)
/MCU/SD_DAT2: J4.1 (DAT2), U9.H2 (GPIO_SD_B0_04)
/MCU/SD_DAT3: J4.2 (DAT3/CD), U9.J2 (GPIO_SD_B0_05)
/MCU/XTALI: C26.1, R14.2, U9.P11 (XTALI), Y1.3
/MCU/XTALO: C25.1, U9.N11 (XTALO), Y1.1
/MCU/~FLASH_CS: U8.1 (~CS), U9.L3 (GPIO_SD_B1_06)
BI_A: U9.K10 (GPIO_AD_B1_07); also elsewhere on the board
BI_B: U9.J12 (GPIO_AD_B1_06); also elsewhere on the board
BI_DOWN: U9.G5 (GPIO_EMC_05); also elsewhere on the board
BI_L: U9.H5 (GPIO_EMC_06); also elsewhere on the board
BI_R: U9.H3 (GPIO_EMC_08); also elsewhere on the board
BI_SEL: U9.A10 (GPIO_B0_11); also elsewhere on the board
BI_ST: U9.D7 (GPIO_B0_00); also elsewhere on the board
BI_UP: U9.F2 (GPIO_EMC_04); also elsewhere on the board
BTN_L: U9.E4 (GPIO_EMC_37); also elsewhere on the board
BTN_PROGRAM: U7.10 (PTB2/IRQ_7); also elsewhere on the board
BTN_R: U9.L14 (GPIO_AD_B0_13); also elsewhere on the board
CV_CLOCK_IN: TP4.1 (1_1), U9.H13 (GPIO_AD_B1_08)
CV_GATE_IN: TP3.1 (1_1), U9.M13 (GPIO_AD_B1_09)
CV_IN: TP5.1 (1_1), U9.M12 (GPIO_AD_B1_03)
ENC_L_A: U9.C10 (GPIO_B0_12); also elsewhere on the board
ENC_L_B: U9.C3 (GPIO_EMC_36); also elsewhere on the board
ENC_R_A: U9.D5 (GPIO_EMC_32); also elsewhere on the board
ENC_R_B: U9.C5 (GPIO_EMC_31); also elsewhere on the board
GEN1: U9.L12 (GPIO_AD_B1_04); also elsewhere on the board
GEN2: U9.C11 (GPIO_B1_02); also elsewhere on the board
GND: C22.2, C23.2, C24.2, C25.2, C26.2, C27.2, C28.2, C29.2, C30.2, C31.2, J4.6 (VSS), J4.SH (SHIELD), J5.6 (VSS), J5.SH (SHIELD), R14.1, R15.1, U5.4 (VSS), U6.4 (VSS), U7.2 (VSS/VREFL), U7.17 (EPAD), U8.4 (VSS), U8.9 (PAD), Y1.2 (G), Y1.4 (G), Y2.3; also elsewhere on the board
I2C_SCL: U9.J11 (GPIO_AD_B1_00); also elsewhere on the board
I2C_SDA: U9.K11 (GPIO_AD_B1_01); also elsewhere on the board
I2S_BCLK: R21.1; also elsewhere on the board
I2S_DATA: R23.1; also elsewhere on the board
I2S_LRCK: R22.1; also elsewhere on the board
LED_MCU: R13.1, U7.11 (PTB3/IRQ_10)
MCP_INTA: TP6.1 (1_1), U9.A11 (GPIO_B1_00)
unnamed: D5.1 (K), R13.2
unnamed: R22.2, U9.L13 (GPIO_AD_B1_10)
unnamed: R21.2, U9.J13 (GPIO_AD_B1_11)
unnamed: TP1.1 (1_1), U9.H12 (GPIO_AD_B1_12)
unnamed: TP2.1 (1_1), U9.H11 (GPIO_AD_B1_13)
unnamed: R23.2, U9.B11 (GPIO_B1_01)
unnamed: TP8.1 (1_1), U9.M14 (GPIO_AD_B0_00)
PSRAM_CLK: U5.6 (SCLK), U6.6 (SCLK), U9.D2 (GPIO_EMC_25)
PSRAM_D0: U5.5 (SI/SIO0), U6.5 (SI/SIO0), U9.B3 (GPIO_EMC_26)
PSRAM_D1: U5.2 (SO/SIO1), U6.2 (SO/SIO1), U9.A2 (GPIO_EMC_27)
PSRAM_D2: U5.3 (SIO2), U6.3 (SIO2), U9.D1 (GPIO_EMC_28)
PSRAM_D3: U5.7 (SIO3), U6.7 (SIO3), U9.E1 (GPIO_EMC_29)
RX: U9.G11 (GPIO_AD_B0_03); also elsewhere on the board
SPDIF_OUT: U9.L11 (GPIO_AD_B1_02); also elsewhere on the board
SPI_MISO: J5.7 (DAT0), R19.2, U9.E7 (GPIO_B0_01)
SPI_MOSI: J5.3 (CMD), R17.2, U9.E8 (GPIO_B0_02)
SPI_SCK: J5.5 (CLK), R18.2, U9.D8 (GPIO_B0_03)
TFT_MOSI: U9.G12 (GPIO_AD_B1_14); also elsewhere on the board
TFT_SCK: U9.J14 (GPIO_AD_B1_15); also elsewhere on the board
TX: U9.M11 (GPIO_AD_B0_02); also elsewhere on the board
USBH_DN: U9.N7 (USB_OTG2_DN); also elsewhere on the board
USBH_DP: U9.P7 (USB_OTG2_DP); also elsewhere on the board
USB_DN: U9.M8 (USB_OTG1_DN); also elsewhere on the board
USB_DP: U9.L8 (USB_OTG1_DP); also elsewhere on the board
VPP3_3: C22.1, C23.1, C24.1, C27.1, C29.1, C31.1, D5.2 (A), J4.4 (VDD), J5.4 (VDD), R16.1, R17.1, R18.1, R19.1, U5.8 (VDD), U6.8 (VDD), U7.1 (VDD/VREFH), U8.8 (VCC); also elsewhere on the board
~I2C_INT: U9.H4 (GPIO_EMC_07); also elsewhere on the board
~MEM_CS: TP7.1 (1_1), U9.D9 (GPIO_B0_10)
~MUTE: U9.D14 (GPIO_B1_13); also elsewhere on the board
~PSRAM1_CS: U5.1 (~CE), U9.D3 (GPIO_EMC_24)
~PSRAM2_CS: U6.1 (~CE), U9.F1 (GPIO_EMC_22)
~SD2_CS: J5.2 (DAT3/CD), R16.2, U9.D13 (GPIO_B1_12)
~TFT_CS: U9.K12 (GPIO_AD_B1_05); also elsewhere on the board
~TFT_DC: U9.D11 (GPIO_B1_03); also elsewhere on the board
~TFT_RESET: U9.K14 (GPIO_AD_B0_12); also elsewhere on the board

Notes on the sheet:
Warning! The MLK02Z32 MCU should be ordered directly from PJRC (pre-programmed with teensy bootloader!) https://www.pjrc.com/store/ic_mkl02_t4.html
ETH Pins Unused

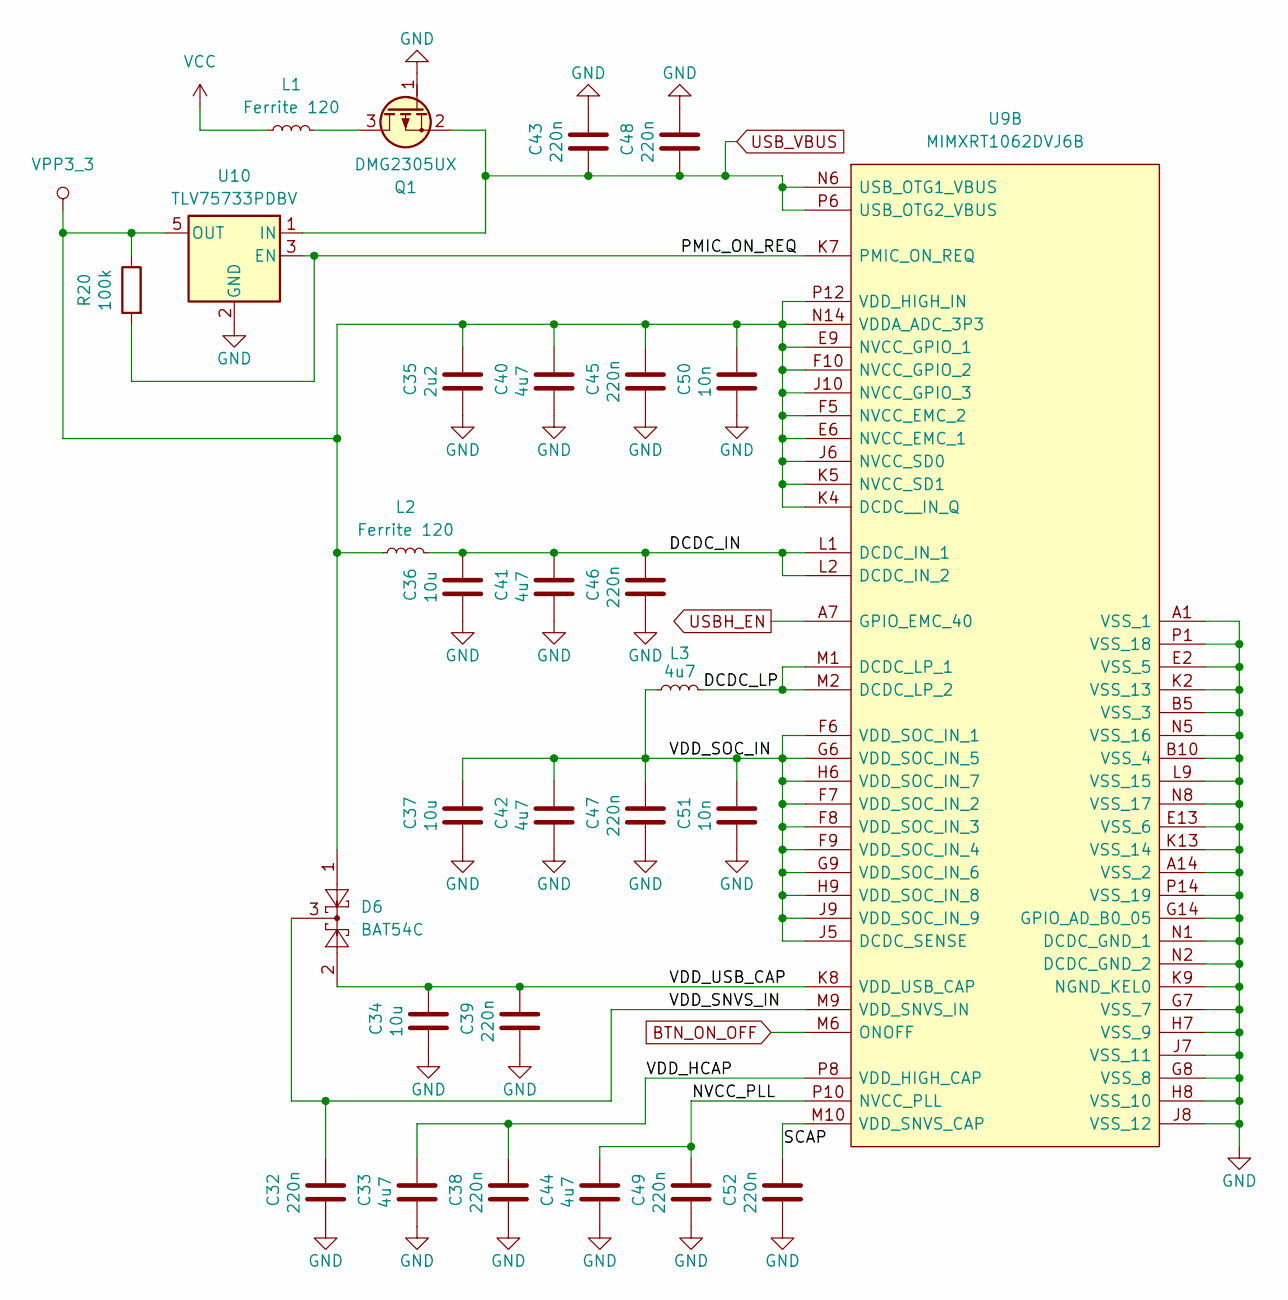
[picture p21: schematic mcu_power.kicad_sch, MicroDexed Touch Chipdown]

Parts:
C32, C38, C39, C43, C45, C46, C48, C49, C52: 220n; C_0805_2012Metric_Pad1.18x1.45mm_HandSolder; LCSC C5378
C33, C40, C41, C44: 4u7; C_0805_2012Metric_Pad1.18x1.45mm_HandSolder; LCSC C1779
C34, C36: 10u; C_0805_2012Metric_Pad1.18x1.45mm_HandSolder; LCSC C15850
C35: 2u2; C_0805_2012Metric_Pad1.18x1.45mm_HandSolder; LCSC C19110
C37: 10u; C_0805_2012Metric; LCSC C1713
C42: 4u7; C_0805_2012Metric; LCSC C1779
C47: 220n; C_0805_2012Metric; LCSC C5378
C50: 10n; C_0805_2012Metric_Pad1.18x1.45mm_HandSolder; LCSC C1710
C51: 10n; C_0805_2012Metric; LCSC C1710
D6: BAT54C; SOT-23_Handsoldering; LCSC C37704
L1, L2: Ferrite 120; L_0805_2012Metric_Pad1.15x1.40mm_HandSolder; LCSC C5671
L3: 4u7; L_0805_2012Metric_Pad1.15x1.40mm; LCSC C63166
Q1: DMG2305UX; SOT-23_Handsoldering; LCSC C144153
R20: 100k; R_0805_2012Metric_Pad1.20x1.40mm_HandSolder; LCSC C25611
U9: MIMXRT1062DVJ6B; BGA196C80P14X14_1200X1200X152; Mouser Part Number 771-MIMXRT1062DVJ6B
U10: TLV75733PDBV; SOT-23-5_HandSoldering; LCSC C485517

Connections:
/MCU Power/DCDC_IN: C36.1, C41.1, C46.1, L2.2, U9.L1 (DCDC_IN_1), U9.L2 (DCDC_IN_2)
/MCU Power/DCDC_LP: L3.2, U9.M1 (DCDC_LP_1), U9.M2 (DCDC_LP_2)
/MCU Power/NVCC_PLL: C44.1, C49.1, U9.P10 (NVCC_PLL)
/MCU Power/PMIC_ON_REQ: R20.2, U9.K7 (PMIC_ON_REQ), U10.3 (EN)
/MCU Power/SCAP: C52.1, U9.M10 (VDD_SNVS_CAP)
/MCU Power/VDD_HCAP: C33.1, C38.1, U9.P8 (VDD_HIGH_CAP)
/MCU Power/VDD_SNVS_IN: C32.1, D6.3, U9.M9 (VDD_SNVS_IN)
/MCU Power/VDD_SOC_IN: C37.1, C42.1, C47.1, C51.1, L3.1, U9.F6 (VDD_SOC_IN_1), U9.F7 (VDD_SOC_IN_2), U9.F8 (VDD_SOC_IN_3), U9.F9 (VDD_SOC_IN_4), U9.G6 (VDD_SOC_IN_5), U9.G9 (VDD_SOC_IN_6), U9.H6 (VDD_SOC_IN_7), U9.H9 (VDD_SOC_IN_8), U9.J5 (DCDC_SENSE), U9.J9 (VDD_SOC_IN_9)
/MCU Power/VDD_USB_CAP: C34.1, C39.1, D6.2, U9.K8 (VDD_USB_CAP)
BTN_ON_OFF: U9.M6 (ONOFF); also elsewhere on the board
GND: C32.2, C33.2, C34.2, C35.2, C36.2, C37.2, C38.2, C39.2, C40.2, C41.2, C42.2, C43.1, C44.2, C45.2, C46.2, C47.2, C48.1, C49.2, C50.2, C51.2, C52.2, Q1.1 (G), U9.A1 (VSS_1), U9.A14 (VSS_2), U9.B5 (VSS_3), U9.B10 (VSS_4), U9.E2 (VSS_5), U9.E13 (VSS_6), U9.G7 (VSS_7), U9.G8 (VSS_8), U9.G14 (GPIO_AD_B0_05), U9.H7 (VSS_9), U9.H8 (VSS_10), U9.J7 (VSS_11), U9.J8 (VSS_12), U9.K2 (VSS_13), U9.K9 (NGND_KEL0), U9.K13 (VSS_14), U9.L9 (VSS_15), U9.N1 (DCDC_GND_1), U9.N2 (DCDC_GND_2), U9.N5 (VSS_16), U9.N8 (VSS_17), U9.P1 (VSS_18), U9.P14 (VSS_19), U10.2 (GND); also elsewhere on the board
unnamed: L1.2, Q1.3 (D)
USBH_EN: U9.A7 (GPIO_EMC_40); also elsewhere on the board
USB_VBUS: C43.2, C48.2, Q1.2 (S), U9.N6 (USB_OTG1_VBUS), U9.P6 (USB_OTG2_VBUS), U10.1 (IN); also elsewhere on the board
VCC: L1.1; also elsewhere on the board
VPP3_3: C35.1, C40.1, C45.1, C50.1, D6.1, L2.1, R20.1, U9.E6 (NVCC_EMC_1), U9.E9 (NVCC_GPIO_1), U9.F5 (NVCC_EMC_2), U9.F10 (NVCC_GPIO_2), U9.J6 (NVCC_SD0), U9.J10 (NVCC_GPIO_3), U9.K4 (DCDC__IN_Q), U9.K5 (NVCC_SD1), U9.N14 (VDDA_ADC_3P3), U9.P12 (VDD_HIGH_IN), U10.5 (OUT); also elsewhere on the board

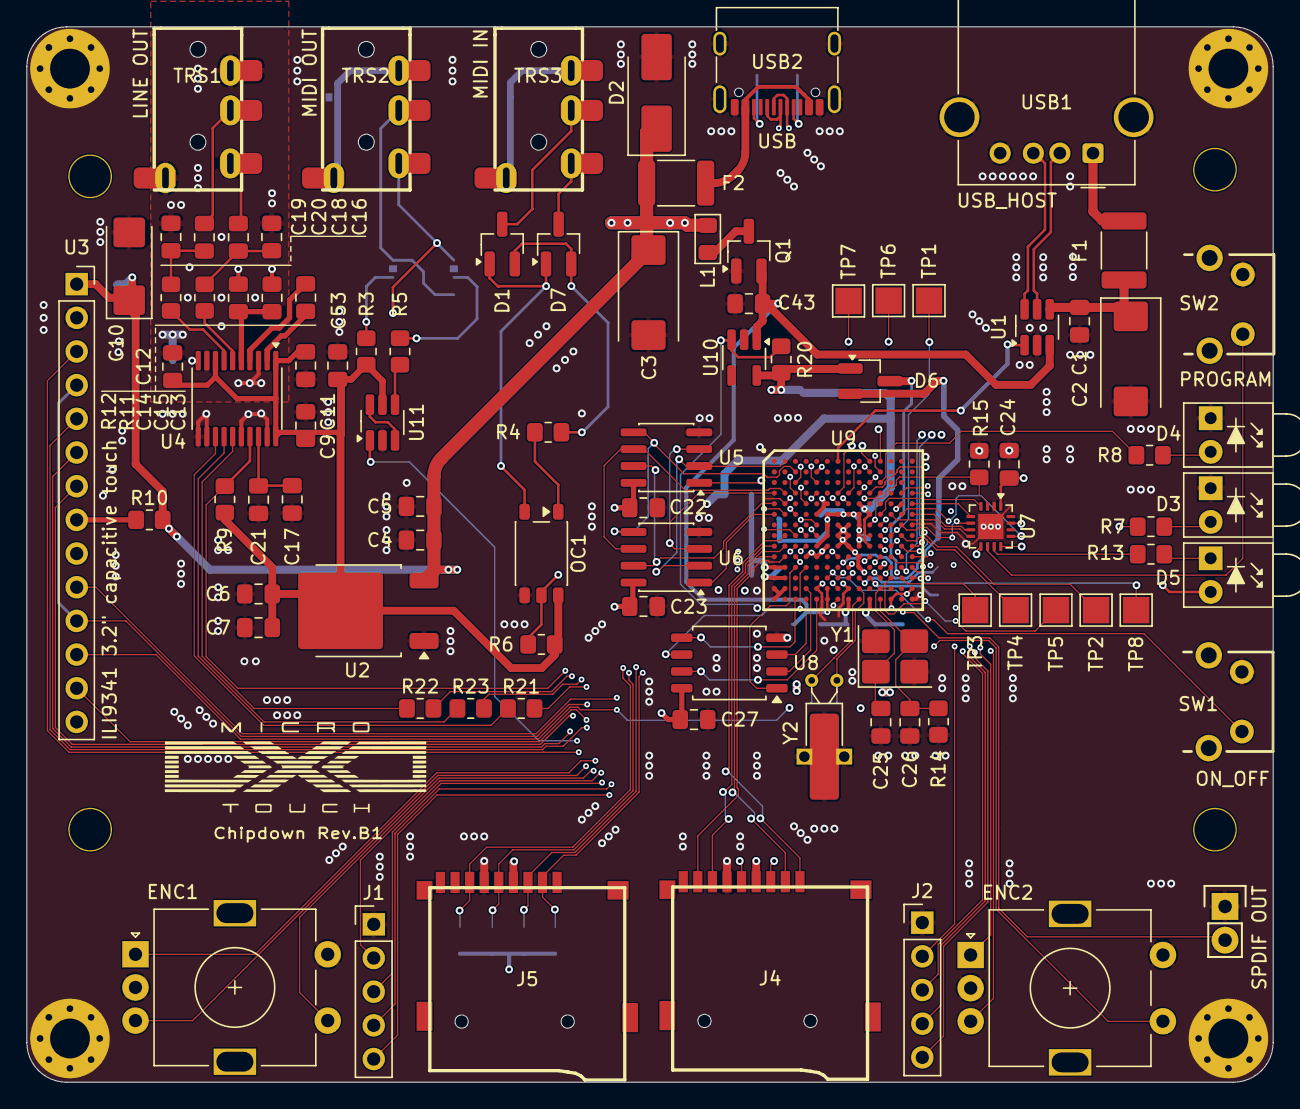
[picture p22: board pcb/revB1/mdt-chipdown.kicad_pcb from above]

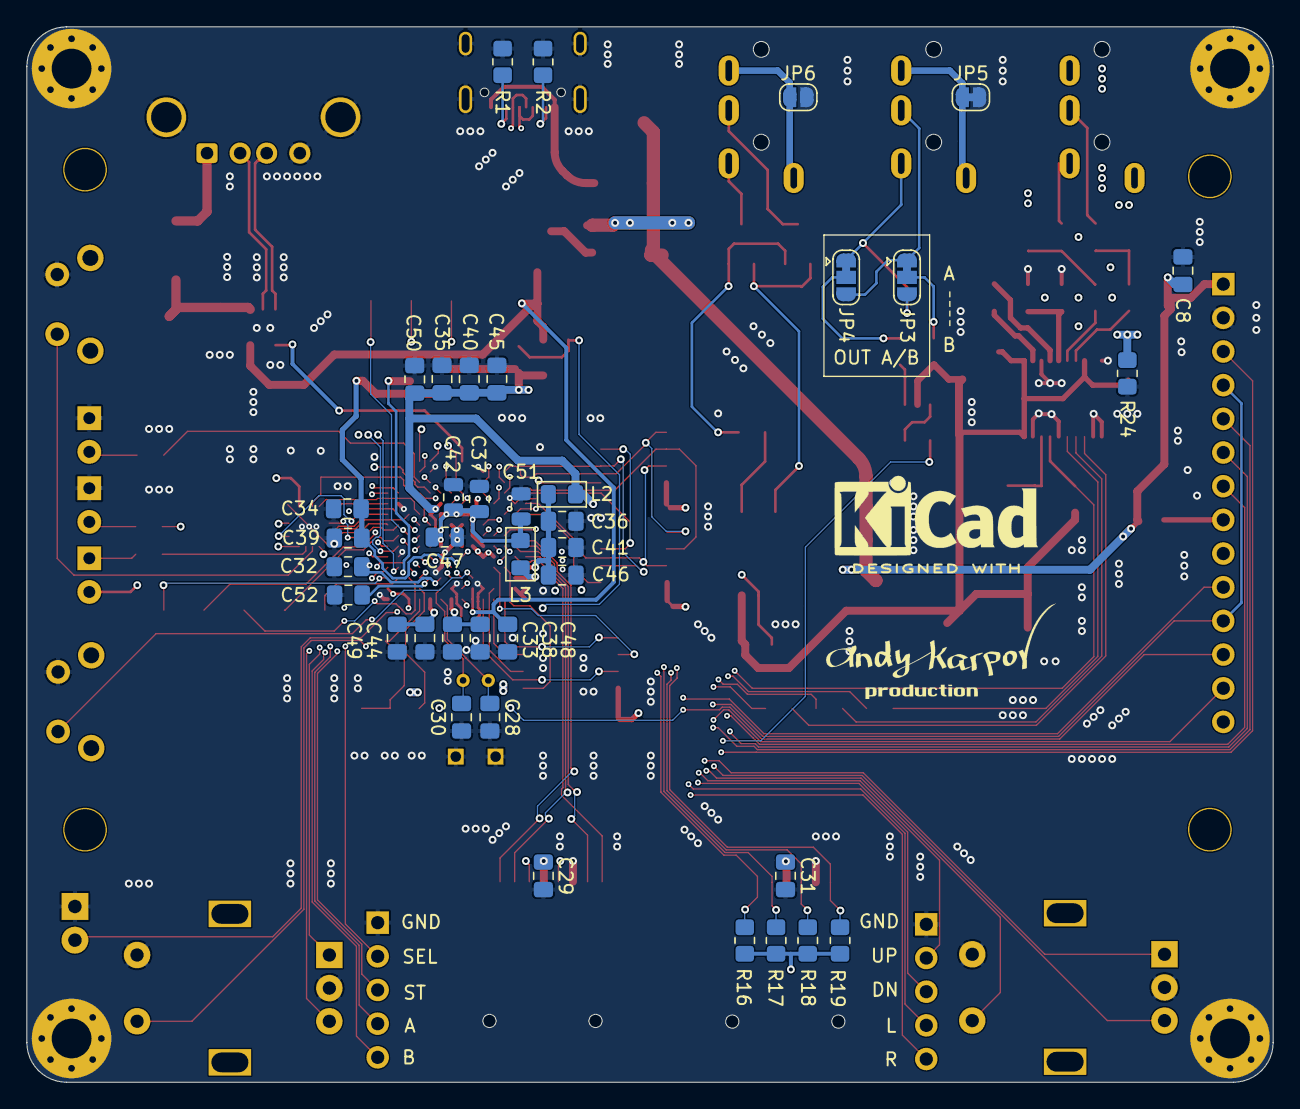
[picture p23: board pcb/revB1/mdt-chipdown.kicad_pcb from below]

Board: 4 copper layers, 94.0 x 79.6 mm, 141 parts (40 on the bottom side), 135 nets.

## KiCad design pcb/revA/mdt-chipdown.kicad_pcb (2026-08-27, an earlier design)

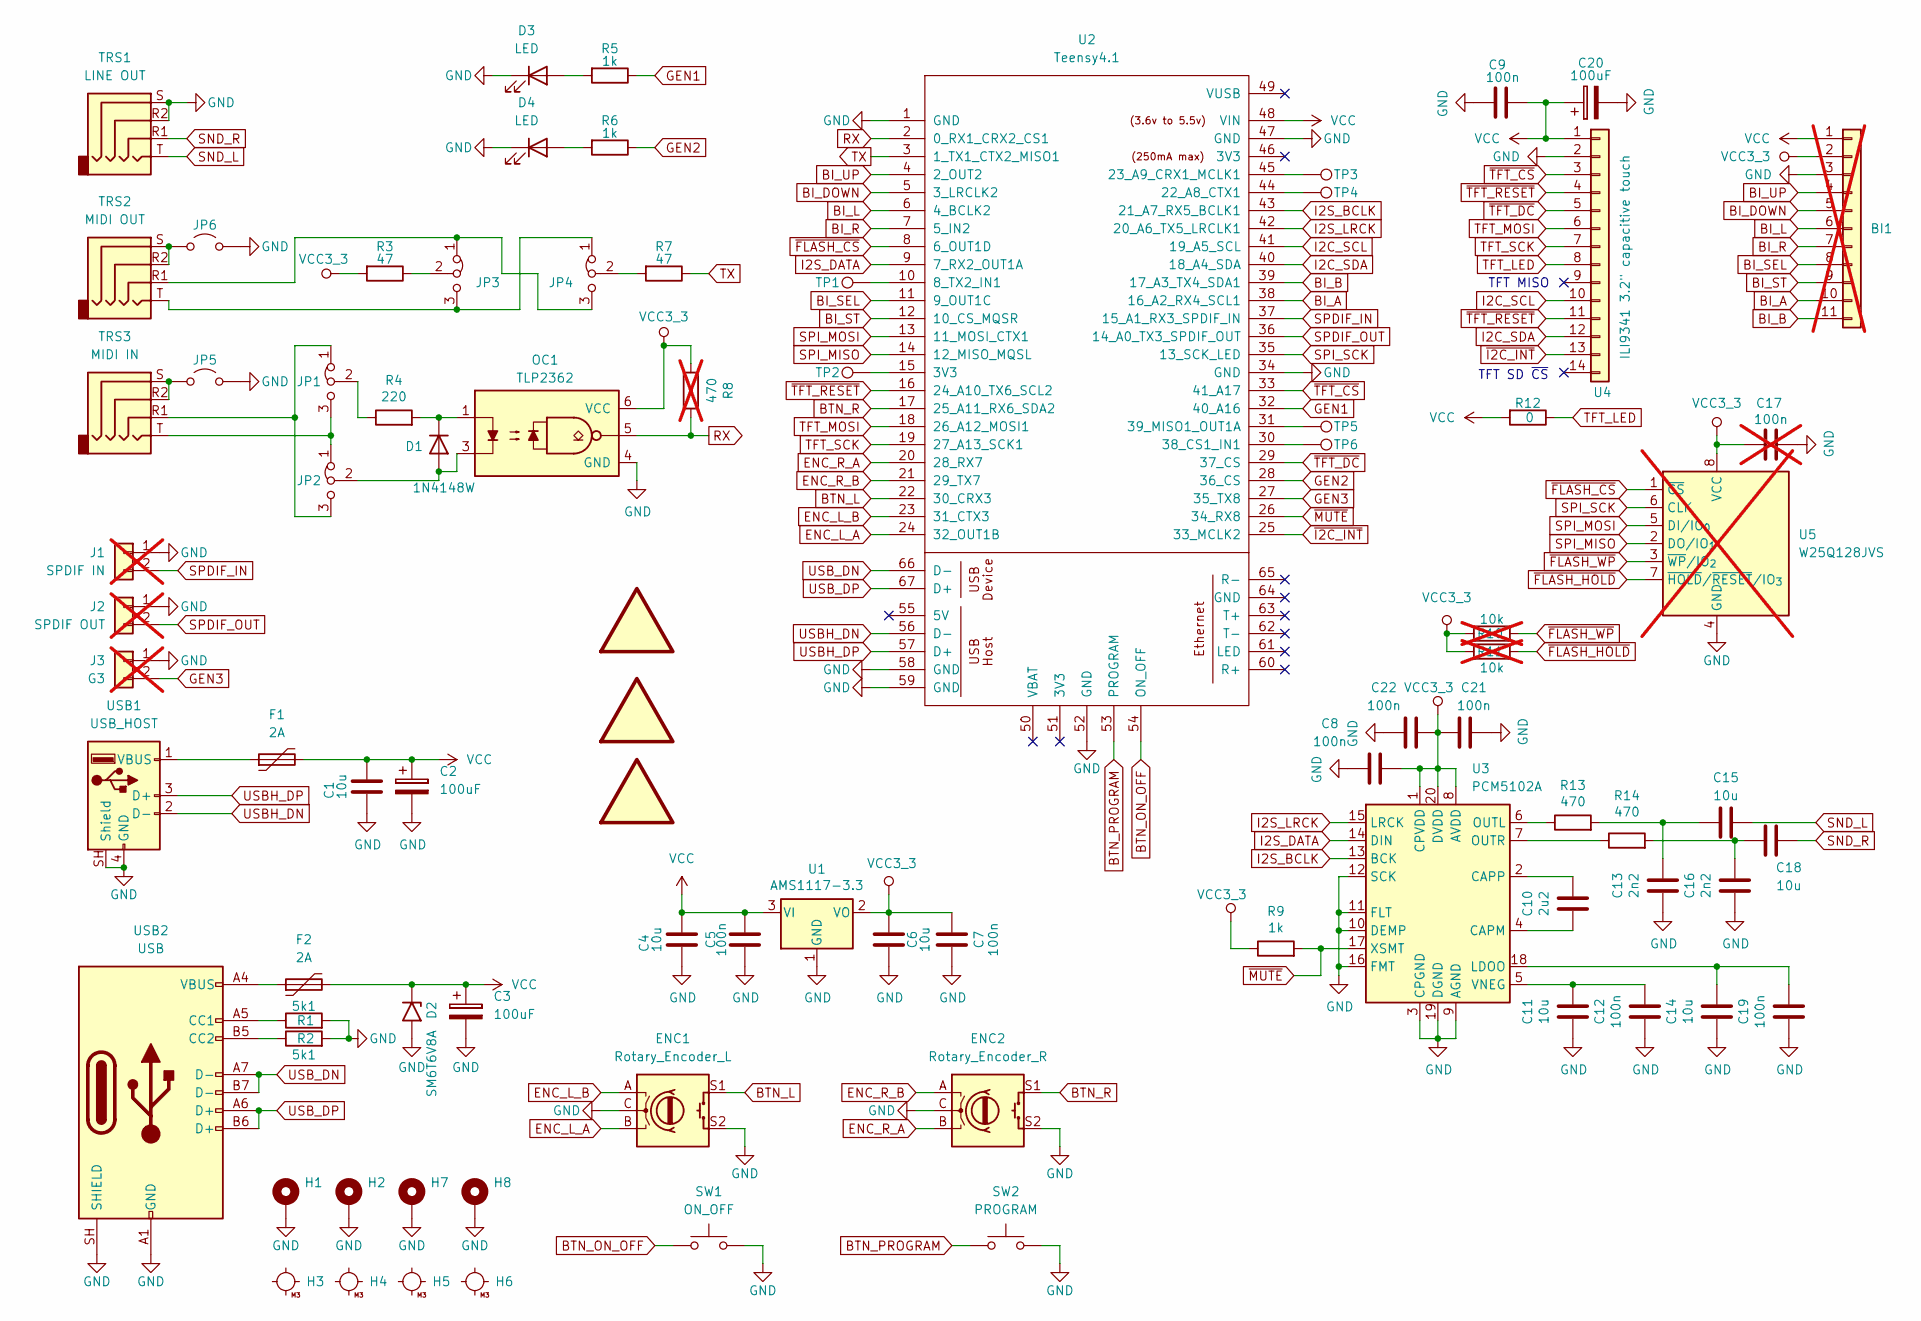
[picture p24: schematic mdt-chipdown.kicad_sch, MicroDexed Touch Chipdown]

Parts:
BI1: Conn_01x11; PinHeader_1x11_P2.54mm_Vertical; not fitted
C1, C4, C6, C11, C14, C15, C18: 10u; C_0805_2012Metric_Pad1.18x1.45mm_HandSolder
C2, C3, C20: 100uF; CP_EIA-6032-28_Kemet-C_HandSolder
C5, C7, C8, C9, C12, C19, C21, C22: 100n; C_0805_2012Metric_Pad1.18x1.45mm_HandSolder
C10: 2u2; C_0805_2012Metric_Pad1.18x1.45mm_HandSolder
C13, C16: 2n2; C_0805_2012Metric_Pad1.18x1.45mm_HandSolder
C17: 100n; C_0805_2012Metric_Pad1.18x1.45mm_HandSolder; not fitted
D1: 1N4148W; D_SOD-123
D2: SM6T6V8A; D_SMB_Handsoldering
D3, D4: LED; LED_Indicator_D3.0mm_W4.6mm_L6.5mm
ENC1: Rotary_Encoder_L; RotaryEncoder_Alps_EC11E-Switch_Vertical_H20mm
ENC2: Rotary_Encoder_R; RotaryEncoder_Alps_EC11E-Switch_Vertical_H20mm
F1, F2: 2A; Fuse_1812_4532Metric_Pad1.30x3.40mm_HandSolder
H1, H2, H7, H8: MountingHole_Pad; MountingHole_3mm_Pad_Via
H3, H4, H5, H6: MountingHole_M3
J1: SPDIF IN; Pin_Header_Straight_1x02; Part Number 1-0201FBV0T; not fitted
J2: SPDIF OUT; Pin_Header_Straight_1x02; Part Number 1-0201FBV0T; not fitted
J3: G3; Pin_Header_Straight_1x02; Part Number 1-0201FBV0T; not fitted
JP1, JP2, JP3, JP4: Jumper_3_Bridged12; SolderJumper-3_P1.3mm_Bridged12_RoundedPad1.0x1.5mm
JP5, JP6: Jumper_2_Open; SolderJumper-2_P1.3mm_Open_RoundedPad1.0x1.5mm
LOGO1: logo; andy_karpov_logo5_silk
LOGO2: logo; KiCad-Logo2_6mm_SilkScreen
LOGO3: logo; microDXD_logo12
OC1: TLP2362; SO-5_4.4x3.6mm_P1.27mm
R1, R2: 5k1; R_0805_2012Metric_Pad1.20x1.40mm_HandSolder
R3, R7: 47; R_0805_2012Metric_Pad1.20x1.40mm_HandSolder
R4: 220; R_0805_2012Metric_Pad1.20x1.40mm_HandSolder
R5, R6, R9: 1k; R_0805_2012Metric_Pad1.20x1.40mm_HandSolder
R8: 470; R_0805_2012Metric_Pad1.20x1.40mm_HandSolder; not fitted
R10, R11: 10k; R_0805_2012Metric_Pad1.20x1.40mm_HandSolder; not fitted
R12: 0; R_0805_2012Metric_Pad1.20x1.40mm_HandSolder
R13, R14: 470; R_0805_2012Metric_Pad1.20x1.40mm_HandSolder
SW1: ON_OFF; Push_PTH_RA_8-020_h7.5mm
SW2: PROGRAM; Push_PTH_RA_8-020_h7.5mm
TP1, TP2, TP3, TP4, TP5, TP6: TestPoint; TestPoint_Pad_2.0x2.0mm
TRS1: LINE OUT; AUDIO_JACK_3.5MM_SMD_TRRS_rounded_mixed
TRS2: MIDI OUT; AUDIO_JACK_3.5MM_SMD_TRRS_rounded_mixed
TRS3: MIDI IN; AUDIO_JACK_3.5MM_SMD_TRRS_rounded_mixed
U1: AMS1117-3.3; TO-252-2
U2: Teensy4.1; Teensy41
U3: PCM5102A; TSSOP-20_4.4x6.5mm_P0.65mm
U4: ILI9341 3.2" capacitive touch; PinSocket_1x14_P2.54mm_Vertical
U5: W25Q128JVS; SOIC-8_5.3x5.3mm_P1.27mm; not fitted
USB1: USB_HOST; USB_A_Molex_67643_Horizontal
USB2: USB; USB_C_Receptacle_G-Switch_GT-USB-7010ASV

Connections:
BI_A: BI1.10, U2.38 (16_A2_RX4_SCL1)
BI_B: BI1.11, U2.39 (17_A3_TX4_SDA1)
BI_DOWN: BI1.5, U2.5 (3_LRCLK2)
BI_L: BI1.6, U2.6 (4_BCLK2)
BI_R: BI1.7, U2.7 (5_IN2)
BI_SEL: BI1.8, U2.11 (9_OUT1C)
BI_ST: BI1.9, U2.12 (10_CS_MQSR)
BI_UP: BI1.4, U2.4 (2_OUT2)
BTN_L: ENC1.S1, U2.22 (30_CRX3)
BTN_ON_OFF: SW1.1, U2.54 (ON_OFF)
BTN_PROGRAM: SW2.1, U2.53 (PROGRAM)
BTN_R: ENC2.S1, U2.17 (25_A11_RX6_SDA2)
ENC_L_A: ENC1.B, U2.24 (32_OUT1B)
ENC_L_B: ENC1.A, U2.23 (31_CTX3)
ENC_R_A: ENC2.B, U2.20 (28_RX7)
ENC_R_B: ENC2.A, U2.21 (29_TX7)
GEN1: R5.1, U2.32 (40_A16)
GEN2: R6.1, U2.28 (36_CS)
GEN3: J3.2, U2.27 (35_TX8)
GND: BI1.3, C1.2, C2.2, C3.2, C4.2, C5.2, C6.2, C7.2, C8.2, C9.2, C11.1, C12.1, C13.1, C14.1, C16.1, C17.2, C19.1, C20.2, C21.1, C22.2, D2.2 (A2), D3.1 (K), D4.1 (K), ENC1.C, ENC1.S2, ENC2.C, ENC2.S2, H1.1 (1_1), H2.1 (1_1), H7.1 (1_1), H8.1 (1_1), J1.1, J2.1, J3.1, JP5.2 (B), JP6.2 (B), OC1.4 (GND), R1.2, R2.2, SW1.2, SW2.2, TRS1.R2, TRS1.S, U1.1 (GND), U2.1 (GND), U2.34 (GND), U2.47 (GND), U2.52 (GND), U2.58 (GND), U2.59 (GND), U3.3 (CPGND), U3.9 (AGND), U3.10 (DEMP), U3.11 (FLT), U3.12 (SCK), U3.16 (FMT), U3.19 (DGND), U4.2, U5.4 (GND), USB1.4 (GND), USB1.SH (Shield), USB2.A1 (GND), USB2.A12 (GND), USB2.B1 (GND), USB2.B12 (GND), USB2.SH (SHIELD)
I2C_SCL: U2.41 (19_A5_SCL), U4.10
I2C_SDA: U2.40 (18_A4_SDA), U4.12
I2S_BCLK: U2.43 (21_A7_RX5_BCLK1), U3.13 (BCK)
I2S_DATA: U2.9 (7_RX2_OUT1A), U3.14 (DIN)
I2S_LRCK: U2.42 (20_A6_TX5_LRCLK1), U3.15 (LRCK)
unnamed: C13.2, C15.2, R13.2
unnamed: C16.2, C18.2, R14.2
unnamed: D1.2 (A), JP2.2 (C), OC1.3
unnamed: D1.1 (K), OC1.1, R4.2
unnamed: D3.2 (A), R5.2
unnamed: D4.2 (A), R6.2
unnamed: F2.1, USB2.A4 (VBUS), USB2.A9 (VBUS), USB2.B4 (VBUS), USB2.B9 (VBUS)
unnamed: JP1.1 (A), JP2.3 (B), TRS3.R1
unnamed: JP1.3 (B), JP2.1 (A), TRS3.T
unnamed: JP1.2 (C), R4.1
unnamed: JP3.1 (A), JP4.3 (B), TRS2.R1
unnamed: JP3.3 (B), JP4.1 (A), TRS2.T
unnamed: JP3.2 (C), R3.1
unnamed: JP4.2 (C), R7.2
unnamed: JP5.1 (A), TRS3.R2, TRS3.S
unnamed: JP6.1 (A), TRS2.R2, TRS2.S
unnamed: TP2.1 (1_1), U2.15 (3V3)
unnamed: TP1.1 (1_1), U2.10 (8_TX2_IN1)
unnamed: TP4.1 (1_1), U2.44 (22_A8_CTX1)
unnamed: TP3.1 (1_1), U2.45 (23_A9_CRX1_MCLK1)
unnamed: TP6.1 (1_1), U2.30 (38_CS1_IN1)
unnamed: TP5.1 (1_1), U2.31 (39_MISO1_OUT1A)
unnamed: C10.1, U3.4 (CAPM)
unnamed: C10.2, U3.2 (CAPP)
unnamed: C14.2, C19.2, U3.18 (LDOO)
unnamed: R13.1, U3.6 (OUTL)
unnamed: R14.1, U3.7 (OUTR)
unnamed: C11.2, C12.2, U3.5 (VNEG)
unnamed: F1.1, USB1.1 (VBUS)
unnamed: R1.1, USB2.A5 (CC1)
unnamed: R2.1, USB2.B5 (CC2)
RX: OC1.5, R8.2, U2.2 (0_RX1_CRX2_CS1)
SND_L: C15.1, TRS1.T
SND_R: C18.1, TRS1.R1
SPDIF_IN: J1.2, U2.37 (15_A1_RX3_SPDIF_IN)
SPDIF_OUT: J2.2, U2.36 (14_A0_TX3_SPDIF_OUT)
SPI_MISO: U2.14 (12_MISO_MQSL), U5.2 (DO/IO_{1})
SPI_MOSI: U2.13 (11_MOSI_CTX1), U5.5 (DI/IO_{0})
SPI_SCK: U2.35 (13_SCK_LED), U5.6 (CLK)
TFT_LED: R12.1, U4.8
TFT_MOSI: U2.18 (26_A12_MOSI1), U4.6
TFT_SCK: U2.19 (27_A13_SCK1), U4.7
TX: R7.1, U2.3 (1_TX1_CTX2_MISO1)
USBH_DN: U2.56 (D-), USB1.2 (D-)
USBH_DP: U2.57 (D+), USB1.3 (D+)
USB_DN: U2.66 (D-), USB2.A7 (D-), USB2.B7 (D-)
USB_DP: U2.67 (D+), USB2.A6 (D+), USB2.B6 (D+)
VCC: BI1.1, C1.1, C2.1, C3.1, C4.1, C5.1, C9.1, C20.1, D2.1 (A1), F1.2, F2.2, R12.2, U1.3 (VI), U2.48 (VIN), U4.1
VCC3_3: BI1.2, C6.1, C7.1, C8.1, C17.1, C21.2, C22.1, OC1.6 (VCC), R3.2, R8.1, R9.1, R10.2, R11.2, U1.2 (VO), U3.1 (CPVDD), U3.8 (AVDD), U3.20 (DVDD), U5.8 (VCC)
~FLASH_CS: U2.8 (6_OUT1D), U5.1 (~CS)
~FLASH_HOLD: R11.1, U5.7 (~HOLD/~RESET/IO_{3})
~FLASH_WP: R10.1, U5.3 (~WP/IO_{2})
~I2C_INT: U2.25 (33_MCLK2), U4.13
~MUTE: R9.2, U2.26 (34_RX8), U3.17 (XSMT)
~TFT_CS: U2.33 (41_A17), U4.3
~TFT_DC: U2.29 (37_CS), U4.5
~TFT_RESET: U2.16 (24_A10_TX6_SCL2), U4.4, U4.11

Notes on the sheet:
TFT SD ~{CS}
TFT MISO

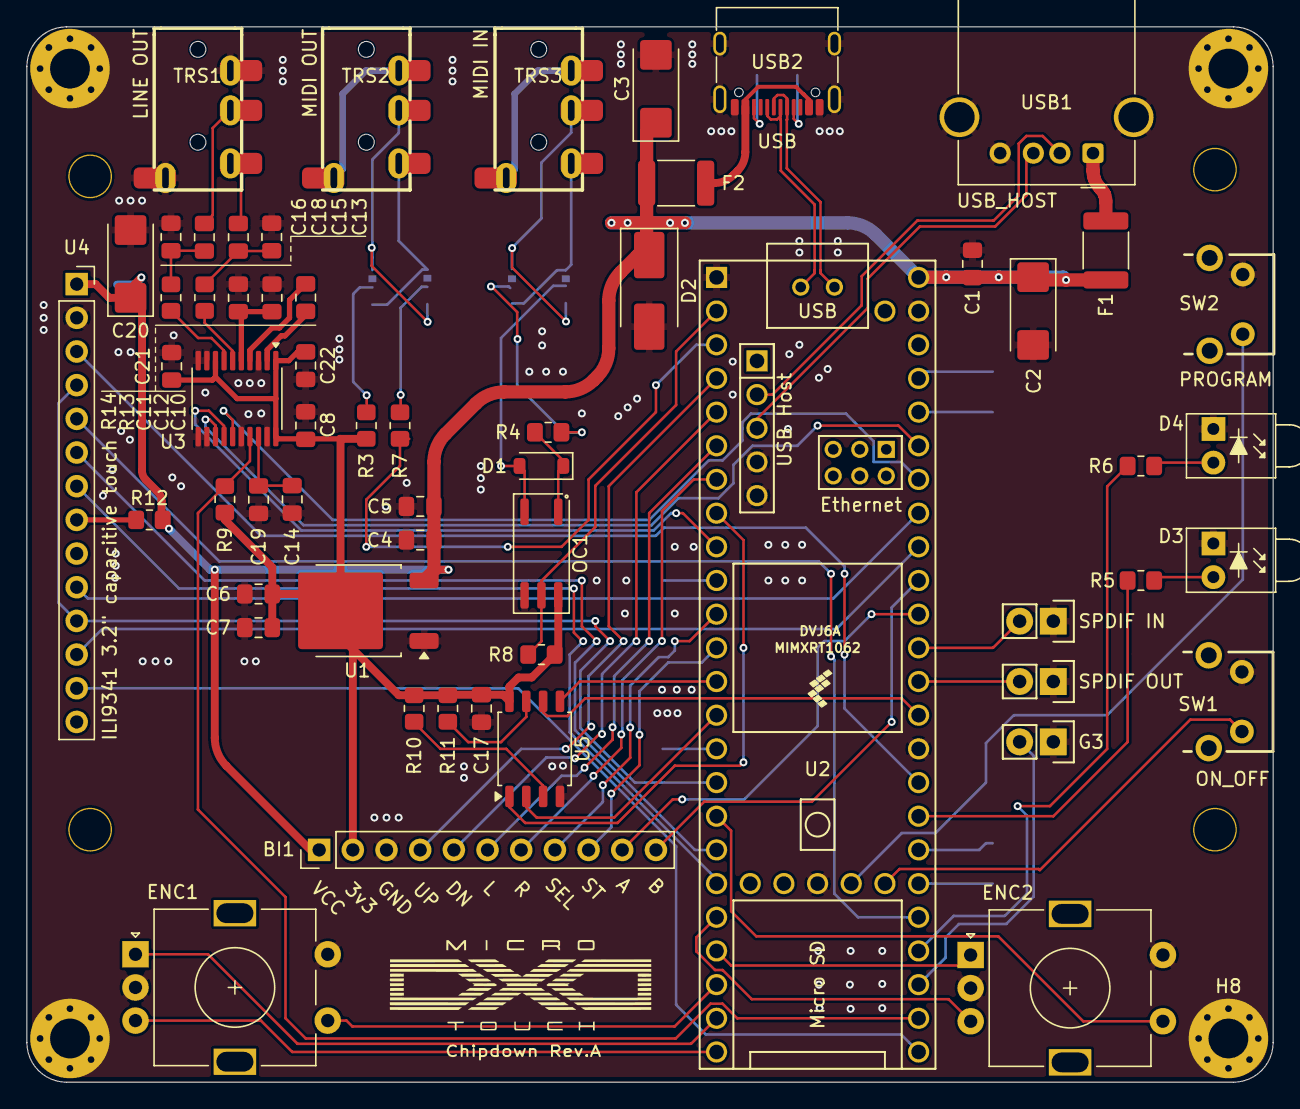
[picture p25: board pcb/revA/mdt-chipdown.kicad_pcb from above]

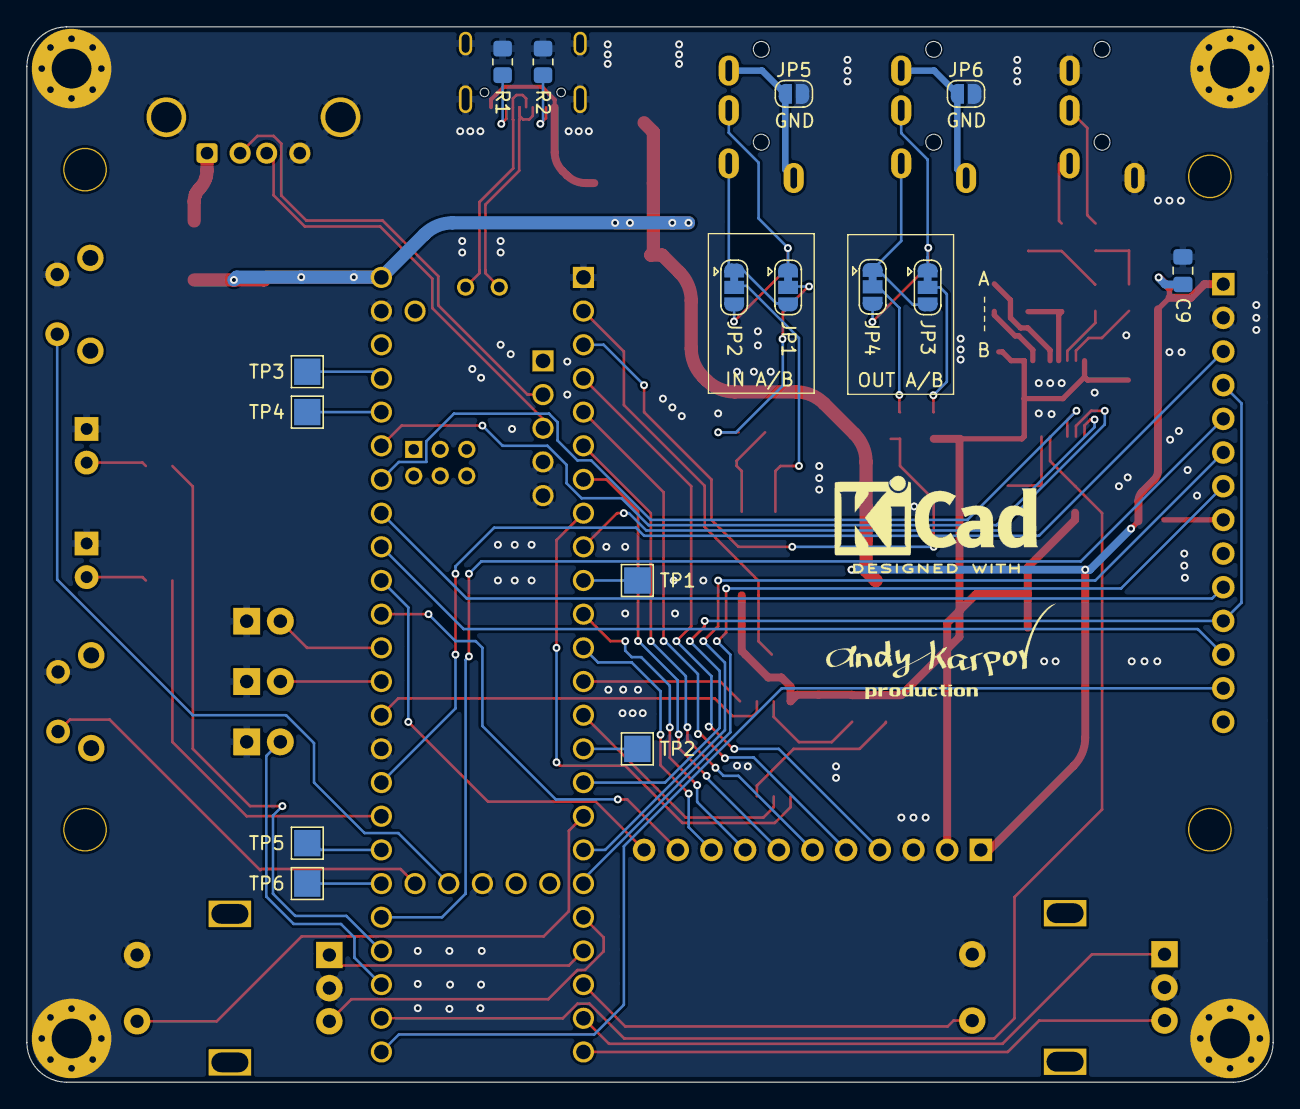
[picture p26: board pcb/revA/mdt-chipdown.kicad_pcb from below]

Board: 2 copper layers, 94.0 x 79.6 mm, 84 parts (17 on the bottom side), 82 nets.

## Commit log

2026-08-07 Case rev.A, wip
    [3_2tft.stl, mdt-chipdown-revA.scad]
2026-08-07 added measurments
    [mdt-chipdown.kicad_pcb]
2026-08-07 Case, release for revA
    [mdt-chipdown-revA-base.stl, mdt-chipdown-revA-lid.stl, mdt-chipdown-revA.scad]
2026-08-08 pcb with embedded 3d models
    [mdt-chipdown.kicad_pcb]
2026-08-08 Added logo
    [mdt-chipdown.kicad_pcb, mdt-chipdown.kicad_sch]
2026-08-08 Added logo to the enclosure
    [mdt-chipdown-revA.scad]
2026-08-08 Updated case release for revA
    [mdt-chipdown-revA-base.stl, mdt-chipdown-revA-lid.stl]
2026-08-24 Rev B (#1)
    * revB wip
    * revB, fully routed
    [mcu.kicad_sch, mcu_power.kicad_sch, mdt-chipdown.kicad_pcb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]
2026-08-24 Fixed gerbers filename typo
2026-08-25 Updated revB: changed vias from 0.4/0.3 to 0.45/0.2
    [mcu_power.kicad_sch, mdt-chipdown.kicad_pcb]
2026-08-25 Added custom field HighlightPins
    [mcu.kicad_sch, mcu_power.kicad_sch, mdt-chipdown.kicad_pcb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]
2026-08-25 Added gerbers for 6-layer pcb order
2026-08-25 Replaced WRL models with STP
    [mdt-chipdown.kicad_pcb]
2026-08-25 Case for revB
    [mdt-chipdown-revB-base.stl, mdt-chipdown-revB-lid.stl, mdt-chipdown-revB.scad]
2026-08-25 Reverted PCB to 4 layers
    [mdt-chipdown.kicad_pcb]
2026-08-27 Updated revA: replaced jumpers with solder jumpers (preconfigured)
    [mdt-chipdown.kicad_pcb, mdt-chipdown.kicad_sch]
2026-08-27 Updated case for revA: reduced display hole, moved down the SD slot a bit
    [mdt-chipdown-revA-base.stl, mdt-chipdown-revA-lid.stl, mdt-chipdown-revA.scad]
2026-08-27 updated revB with solder jumpers
    [mcu.kicad_sch, mcu_power.kicad_sch, mdt-chipdown.kicad_pcb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]
2026-08-28 Added (unverified yet) production files for JLC PCBA
    [BOM-mdt-chipdown.csv, mcu.kicad_sch, mcu_power.kicad_sch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]
2026-08-28 Added AGND
    [mdt-chipdown.kicad_pcb]
2026-08-30 Updated revB1
    [mcu.kicad_sch, mcu_power.kicad_sch, mdt-chipdown.kicad_pcb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]
